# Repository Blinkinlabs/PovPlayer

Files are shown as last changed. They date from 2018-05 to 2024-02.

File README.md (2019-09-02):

# PovPlayer

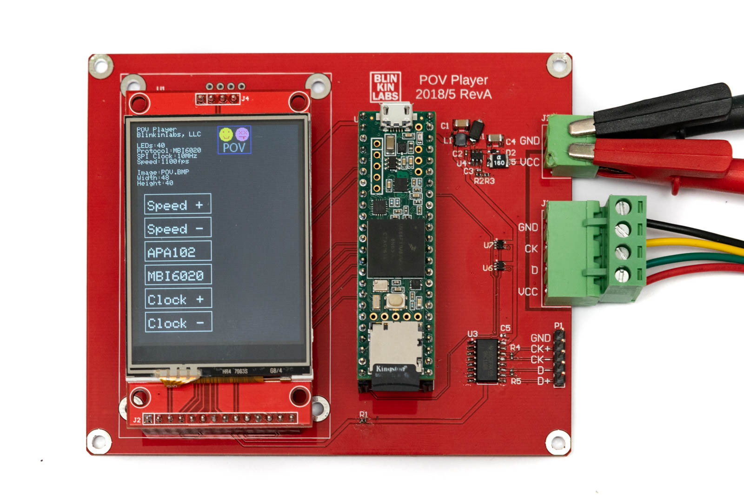
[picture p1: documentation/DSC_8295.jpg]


POV player is a test tool for displaying POV images. It's based on a Teensy 3.6, and uses a generic SPI touchscreen to configure the POV settings.

A PCB file is included, however the project can be built using short jumper wires if desired.

# Hardware needed

* [Teensy 3.6](https://www.pjrc.com/store/teensy36.html)
* [Generic 2.8" SPI touchscreen](https://www.amazon.com/HiLetgo-240X320-Resolution-Display-ILI9341/dp/B073R7BH1B), using ILI9341 driver
* (optional) PCB made from the [project gerbers](https://github.com/Blinkinlabs/PovPlayer/blob/master/releases/2018-05-29%20POV_Player%20RevA%20Gerber.zip)

# Software Setup

Install:

*  [Arduino](https://www.arduino.cc/)
*  [Teensyduino](https://www.pjrc.com/teensy/teensyduino.html)
*  Adafruit_ILI9341 library for Arduino- this might come with Teensyduino
*  XPT2046_Touchscreen library for Arduino- this might come with Teensyduino

Download or clone this respoitory, then open the [project sketch sketch](https://github.com/Blinkinlabs/PovPlayer/tree/master/SPI_POV) in Arduino and upload it to the Teensy 3.6

# Usage

See the [Usage manual](https://github.com/Blinkinlabs/PovPlayer/raw/master/releases/2018-06-05%20POV%20Player%20Manual%20RevA.pdf)

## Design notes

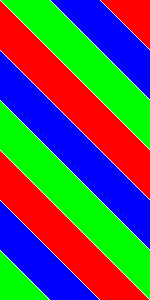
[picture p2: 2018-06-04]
sample images/rgb stripes.bmp

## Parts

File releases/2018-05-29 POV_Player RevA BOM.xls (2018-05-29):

PartType | Designator | Comment | Description | ComponentLink2URL | Pins | LibRef | Manufacturer | Quantity | Model:Footprint
CAP 47uF 16V 1210(3225) | C1, C4 | CAP 47uF 16V 1210(3225) | CAP 47uF 16V ±20% 1210 (3225 Metric) Thickness 2.8mm SMD |  | 2.0 | CMP-1038-02296-1 |  | 2.0 | Chip Capacitor, Body 3.2x2.5mm, Height 2.8mm, IPC High Density
CAP 100nF 25V 0402(1005) | C2 | CAP 100nF 25V 0402(1005) | CAP 100nF 25V ±20% 0402 (1005 Metric) Thickness 0.6mm SMD |  | 2.0 | CMP-1034-02073-1 |  | 1.0 | Chip Capacitor, Body 1.0x0.5mm, Height 0.6mm, IPC High Density
CAP 33pF 25V 0402(1005) | C3 | CAP 33pF 25V 0402(1005) | CAP 33pF 25V ±5% 0402 (1005 Metric) Thickness 0.6mm SMD |  | 2.0 | CMP-1034-00998-1 |  | 1.0 | Chip Capacitor, Body 1.0x0.5mm, Height 0.6mm, IPC High Density
CAP 100nF 10V 0402(1005) | C5 | CAP 100nF 10V 0402(1005) | CAP 100nF 10V ±10% 0402 (1005 Metric) Thickness 0.6mm SMD |  | 2.0 | CMP-1034-02065-1 |  | 1.0 | Chip Capacitor, Body 1.0x0.5mm, Height 0.6mm, IPC High Density
1N4148WT | D1, D2 | 1N4148WT | High Conductance Fast Switching Diode, 75 V, -55 to 150 degC, 2-Pin SOD523F, RoHS | http://www.fairchildsemi.com/ds/1N/1N4148WT.pdf | 2.0 | CMP-0881-00001-1 | Fairchild Semiconductor | 2.0 | SMD, 2-Leads, Body 1.2x0.8mm, Height 0.7mm
1757268 | J1 | 1757268 | TERM BLOCK HDR 4POS 90DEG 5.08MM | 1757268_06_en_00.pdf | 4.0 | 1757268 | Phoenix Contact | 1.0 | TERM BLOCK HDR 4POS 90DEG 5.08MM
Power In | J2 | Power In | TERM BLOCK HDR 2POS 90DEG 5.08MM | 1757268_06_en_00.pdf | 2.0 | 1757242 | Phoenix Contact | 1.0 | TERM BLOCK HDR 2POS 90DEG 5.08MM
SWPA3010S100MT | L1 | SWPA3010S100MT | Wire Wound SMD Power Inductors 3010 3.0×3.0×1.0 10uH, .75A |  | 2.0 | SWPA3010S100MT |  | 1.0 | Wire Wound SMD Power Inductor 3.0×3.0×1.0
PHT-105-02-L-S | P1 | PHT-105-02-L-S | Press Fit Header, Through-hole, Vertical, -55 to 125 degC, 2.54 mm Pitch, 5-Pin, Male, RoHS | http://www.samtec.com/documents/webfiles/pdf/pht.pdf | 5.0 | CMP-1024-00186-1 | Samtec | 1.0 | Press Fit Socket Assembly, 1x5 Pins, Vertical, 2.54mm Pitch, Male
47R 5% 0402(1005) | R1 | 47R 5% 0402(1005) | 47R 0.063W 5% 0402 (1005 Metric) SMD |  | 2.0 | CMP-1011-00042-1 |  | 1.0 | Chip Resistor, Body 1.0x0.5mm, IPC Medium Density
127K 1% 0402(1005) | R2 | 127K 1% 0402(1005) | 127K 0.063W 1% 0402 (1005 Metric) SMD |  | 2.0 | CMP-1011-00747-1 |  | 1.0 | Chip Resistor, Body 1.0x0.5mm, IPC High Density
23K7 1% 0402(1005) | R3 | 23K7 1% 0402(1005) | 23K7 0.063W 1% 0402 (1005 Metric) SMD |  | 2.0 | CMP-1011-00663-1 |  | 1.0 | Chip Resistor, Body 1.0x0.5mm, IPC High Density
120R 5% 0402(1005) | R4, R5 | 120R 5% 0402(1005) | 120R 0.063W 5% 0402 (1005 Metric) SMD |  | 2.0 | CMP-1011-00052-1 |  | 2.0 | Chip Resistor, Body 1.0x0.5mm, IPC Medium Density
2.4" SPI LCD ILI9341 | U1 | 2.4" SPI LCD ILI9341 | Generic 2.4 inch SPI LCD TFT serial module 240x320 with touch ILI9341 |  | 18.0 | 2.4" SPI LCD ILI9341 |  | 1.0 | Generic 2.4 inch SPI LCD TFT serial module 240x320 with touch ILI9341
TEENSY_3.6 | U2 | TEENSY_3.6 | Teensy 3.6 |  | 48.0 | TEENSY_3.6 |  | 1.0
SN65C1168ENS | U3 | SN65C1168ENS | Dual Differential Driver and Receiver with +/-15-kV IEC ESD Protection, 2 TX / 2 RX, 5V, -40 to 85 degC, 16-Pin SO (NS), Green (RoHS & no Sb/Br) | http://www.ti.com/litv/pdf/msop002a | 16.0 | CMP-0310-00409-2 | Texas Instruments | 1.0 | SOIC,16-Leads,Body 10.5x5.6mm,Pitch 1.27mm,IPC Medium Density
BL9352A | U4 | BL9352A | 45V, 1.6MHz, 600mA Step-Down Converter |  | 6.0 | BL9352A |  | 1.0 | SOT23, 6-Leads, Body 2.92x2.80mm, Pitch 0.95mm, IPC Medium Density
nSMD020-30V | U5 | nSMD020-30V | 0.2A 30V Self-healing fuse |  | 2.0 | nSMD020-30V | Alpha-Top Technology Corp. | 1.0 | 0.2A 30V Self-healing fuse
74LVC1G17GW | U6, U7 | 74LVC1G17GW | Single Schmitt Trigger Buffer, 1.65 to 5.5 V, -40 to 125 degC, 5-Pin TSSOP (SOT353-1), RoHS, Tape and Reel |  | 5.0 | CMP-2000-05689-1 | NXP Semiconductors | 2.0 | TSSOP, 5-Leads, Body 2.25x1.35mm, Pitch 0.65mm, IPC High Density

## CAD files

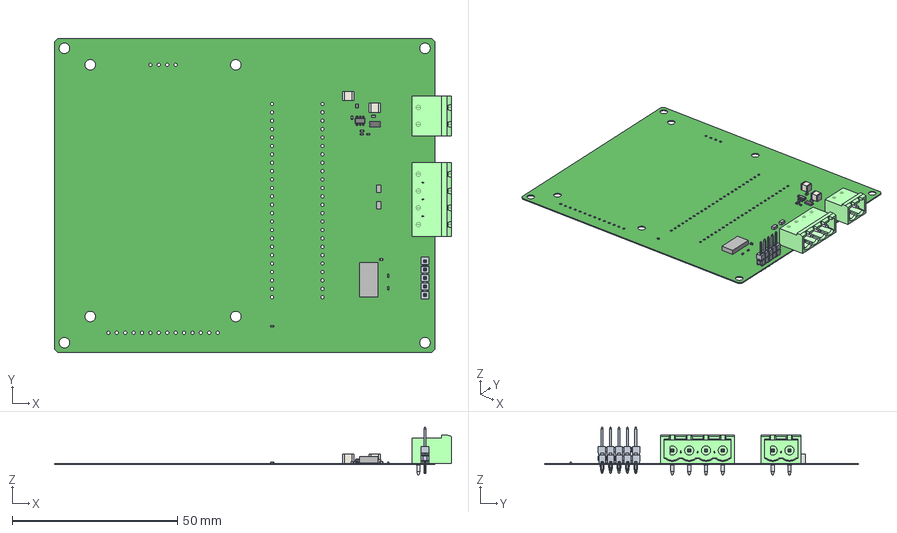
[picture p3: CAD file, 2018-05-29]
releases/2018-05-29 POV_Player RevA.step
120.0 x 95.0 x 14.4 mm
Board
Extruded x 35
Fuse_1206_v1
Open_CASCADE_STEP_translator_6.8_3.1.1
Leader x 6
PHT-105-02-X-S
mstba_2.5-2-g-5.08
mstba_2.5-4-g-5.08

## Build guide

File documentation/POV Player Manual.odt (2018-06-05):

POV Player

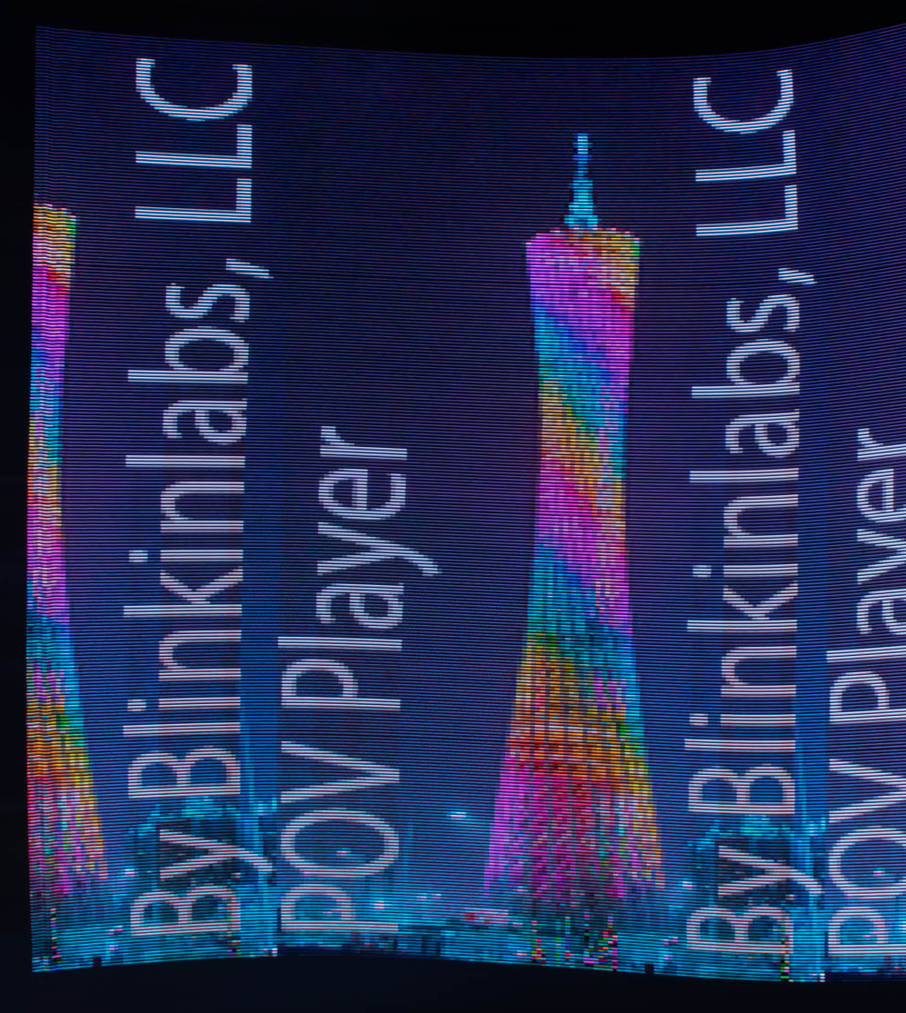
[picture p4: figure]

Blinkinlabs LLC
Revision A 2018/06/05

# Introduction

The POV Player is a prototyping tool for developing a persistence of vision artwork.

Specifications:

- Maximum LED count: 500 LEDs
- Outputs: 1
- Typical framerate (output lines per second): 1100
- Maximum POV image size: Maximum ~150kB (500 RGBLEDs x 100frames)
- Maximum SPI output speed: 30MHz
- Input power range: 5-24V
- Image format: 24-bit uncompressed bitmap

It supports the following LED types:

- APA102/SK9822
- MBI6020 (used in dot pixel product)

# Absolute Maximum Ratings

The absolute maximum ratings indicated sustained limits beyond which damage to the device may occur.

Parameter | Description | Min | Max | Units
VCC | Input Voltage (J2 connector) | -0.3 | 28 | V
ILED | LED output current (J1 connector) | | 10 | A

# Recommended Operating Conditions

For proper operation, the device should be used within the recommended conditions.

Parameter | Description | Min | Max | Units
VCC | Input Voltage (J2 connector) | 5 | 24 | V
ILED | LED output current (J1 connector) | | 8 | A

*Note: The POV Player is designed to be powered from whatever power supply is used for the LEDs. For APA102/SK9822 strips, this is usually 5V. For the Dot Pixels (MBI6020), the pixels are powered from AC power, so an external power supply should be used. The 12V supply in the existing control box can be used to power the player.

# Quick start guide

1. Connect either the SK9822 or Dot Pixels, using the steps listed in the section ‘Connection diagram (Dot Pixels)’ or ‘Connection diagram (SK9822 strip)’.
2. If the microSD card is inserted in the player, remove it.
3. Power on the unit. By default, it will play back a slow test pattern, cycling up to 500 LEDs through red, green, and blue. Note that the default protocol is MBI6020, so if an SK9822 strip is attached, you will need to follow the instructions in the ‘Status Information’ section to switch to APA102/SK9822 mode.
4. Use the instructions in the ‘Status Information’ guide to test adjusting the playback speed and clock speed. Also Try increasing the clock speed until the LEDs no longer update properly- that will show the maximum speed supported by the hardware.
5. Once the setup is working with the demo pattern, the next step is to load a POV image. Prepare a microSD card with an image using the steps listed in the section ‘Image preparation’
6. Place the microSD card in the controller, and turn the power back on.
7. Enjoy the POV effect!

# Image Preparation

The POV player can load a single POV image from the microSD card. The image must be formatted as a 24-bit, uncompressed bitmap. The LED count is determined by the image height, and the number of POV frames is determined by the image width. For example, if there are 40 LEDs in the system, an image with height 40 should be used. If a small image should be repeated multiple times along the LED strip, simply create an image with multiple copies arranged in a vertical row.

Here are the steps for exporting a compatible bitmap image from Photoshop:

1. Insert the microSD card into the computer.
2. Launch photoshop, then load the desired image.
3. From the file menu, select ‘Save As’
4. On the ‘Save as type’ option, select ‘BMP’
5. Change the image name to ‘pov.bmp’, and select the root of the SD card drive (for example E:\ on Windows) as the location to save it. Click ‘Save’
6. On the ‘BMP Options’ dialog, make sure the File Format is set to ‘Windows’, the Depth is set to ‘24 Bit’, and no other options are selected. Click ‘OK’
7. Eject the microSD card from the computer, and place it in the Player.

# Connection diagram (Dot Pixels)

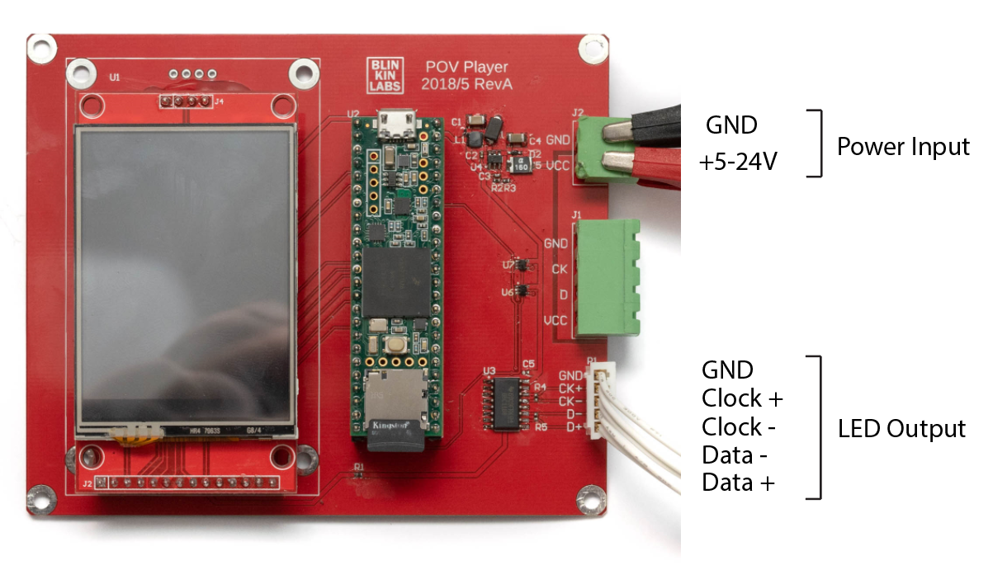
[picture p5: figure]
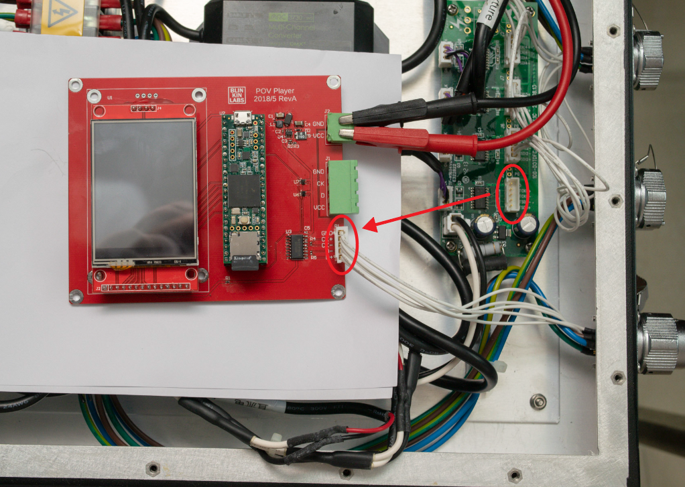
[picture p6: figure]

For Dot Pixels, connect a 5-24V power supply to the connector J2. The 12V supply inside the existing metal control box can be used for this. Then, disconnect the white cable from inside the metal control box, and connect it to output P1. Be sure to plug the connector in the right orientation- the pins are labeled on both the original adapter board and the POV Player. In this configuration, the LED power is connected directly to the dot pixel strip, bypassing the POV player.

Note: The P1 connector outputs an RS422 differential signal, suitable for controlling the Dot Pixel samples.

Caution: The Dot Pixels are powered by 220V AC wall power. Be extremely careful when working with this style of pixel, and be sure to mount the POV Player such that none of its electrical connections touch any of the connections in the existing controller box.

# Connection diagram (SK9822 strip)

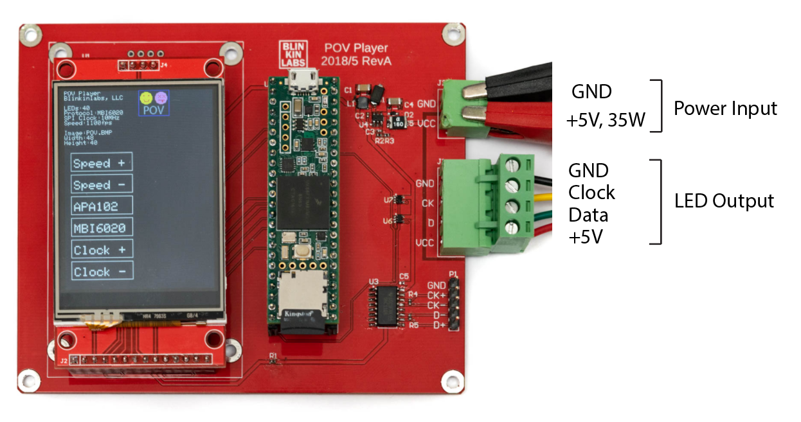
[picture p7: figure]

For SK9822 strip, connect a 5V power supply rated at 35W (7A) or greater to the connector J2. Then, connect the SK9822 strip to the connector J2. In this configuration, the LED strip is powered directly from the board, so no further wiring is needed.

Note: The J1 connector outputs a single ended, 5V TTL signal suitable for common LED strips.

# Status Interface

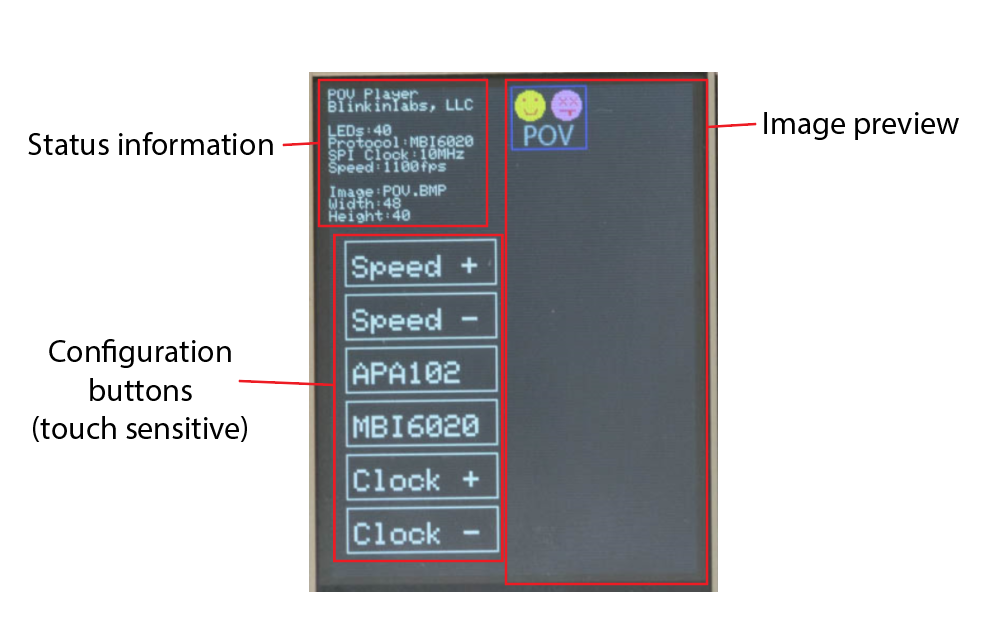
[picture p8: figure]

## Status Information

The status information section displays the current LED configuration, including LED count, protocol, SPI clock speed, image file name, and image dimensions.

## Configuration Buttons

The POV player can be configured by using the on-screen buttons. Simply press a button to change it’s setting.

Button | Description
SPEED + | Increase the POV Speed. If the POV speed is less than 10, it will be incremented by 1 each time the button is pressed. If the POV speed is between 10 and 100, it will be increased by 10 each time the button is pressed. If the POV speed is equal to or greater than 100, it will be incremented by 100 each time the button is pressed.
SPEED - | Decrease the POV Speed. If the POV speed is less than or equal to 10, it will be decremented by 1 each time the button is pressed. If the POV speed is between 11 and 100, it will be decremented by 10 each time the button is pressed. If the POV speed is greater than 100, it will be decremented by 100 each time the button is pressed. The minimum POV speed is 1.
APA102 | Switch the output protocol to APA102/SK9822 mode. Pressing this will also reset the SPI Clock setting to 16MHz.
MBI6020 | Switch the output protocol to MBI6020 mode. Pressing this will also reset the SPI Clock setting to 10MHz. Note that the dot pixels should be connected to the player and powered on before switching to this mode, because the player needs to send configuration information to them before they can be used. Also note that the MBI6020 controllers in the dot pixels can become unresponsive, if data from a different output protocol is sent to them. In that case, turn the AC power off and then on again to reset the dot pixel controllers.
Clock + | Increase the SPI clock speed. The speed will be increased by 1 MHz each time the button is pressed. The maximum workable speed that the player can output depends on the LED type.
Clock - | Decrease the SPI clock speed. The speed will be decreased by 1 MHz each time the button is pressed. The minimum clock speed is 1 MHz.

## Image Preview

The image preview shows a color representation of the image that is currently displayed on the screen. If the image is larger than 118x318, only the top-left corner of the image will be shown on the screen, however the full image will still be sent to the pixels.

Blinkinlabs, LLC 7/7 POV Player Rev A, 2018/06/05

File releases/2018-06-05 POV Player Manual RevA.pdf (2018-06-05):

# POV Player

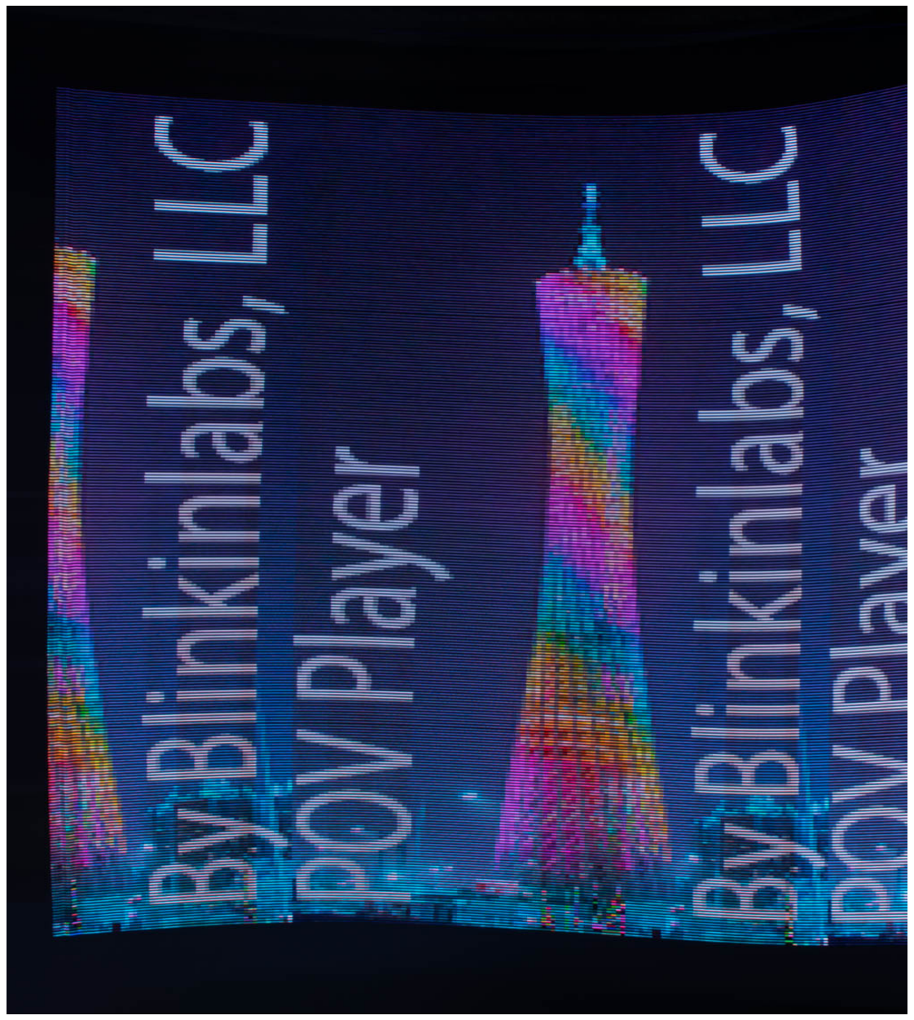
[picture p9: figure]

## Blinkinlabs LLC Revision A 2018/06/05

## 1 Introduction

The POV Player is a prototyping tool for developing a persistence of vision artwork.

Specifications:
- Maximum LED count: 500 LEDs
- Outputs: 1
- Typical framerate (output lines per second): 1100
- Maximum POV image size: Maximum ~150kB (500 RGBLEDs x 100frames)
- Maximum SPI output speed: 30MHz
- Input power range: 5-24V
- Image format: 24-bit uncompressed bitmap

It supports the following LED types:
- APA102/SK9822
- MBI6020 (used in dot pixel product)

## 2 Absolute Maximum Ratings

The absolute maximum ratings indicated sustained limits beyond which damage to the device may occur.
Parameter | Description | Min | Max | Units
VCC | Input Voltage (J2 connector) | -0.3 | 28 | V
ILED | LED output current (J1 connector) | | 10 | A

## 3 Recommended Operating Conditions

For proper operation, the device should be used within the recommended conditions.
Parameter | Description | Min | Max | Units
VCC | Input Voltage (J2 connector) | 5 | 24 | V
ILED | LED output current (J1 connector) | | 8 | A
*Note: The POV Player is designed to be powered from whatever power supply is used for the LEDs. For APA102/SK9822 strips, this is usually 5V. For the Dot Pixels (MBI6020), the pixels are powered from AC power, so an external power supply should be used. The 12V supply in the existing control box can be used to power the player.
Blinkinlabs, LLC | 2/7 | POV Player Rev A, 2018/06/05

## 4 Quick start guide

1. Connect either the SK9822 or Dot Pixels, using the steps listed in the section ‘Connection diagram (Dot Pixels)’ or ‘Connection diagram (SK9822 strip)’.
2. If the microSD card is inserted in the player, remove it.
3. Power on the unit. By default, it will play back a slow test pattern, cycling up to 500 LEDs through red, green, and blue. Note that the default protocol is MBI6020, so if an SK9822 strip is attached, you will need to follow the instructions in the ‘Status Information’ section to switch to APA102/SK9822 mode.
4. Use the instructions in the ‘Status Information’ guide to test adjusting the playback speed and clock speed. Also Try increasing the clock speed until the LEDs no longer update properly- that will show the maximum speed supported by the hardware.
5. Once the setup is working with the demo pattern, the next step is to load a POV image. Prepare a microSD card with an image using the steps listed in the section ‘Image preparation’
6. Place the microSD card in the controller, and turn the power back on.
7. Enjoy the POV effect!

## 5 Image Preparation

The POV player can load a single POV image from the microSD card. The image must be formatted as a 24-bit, uncompressed bitmap. The LED count is determined by the image height, and the number of POV frames is determined by the image width. For example, if there are 40 LEDs in the system, an image with height 40 should be used. If a small image should be repeated multiple times along the LED strip, simply create an image with multiple copies arranged in a vertical row.

Here are the steps for exporting a compatible bitmap image from Photoshop:

1. Insert the microSD card into the computer.
2. Launch photoshop, then load the desired image.
3. From the file menu, select ‘Save As’
4. On the ‘Save as type’ option, select ‘BMP’
5. Change the image name to ‘pov.bmp’, and select the root of the SD card drive (for example E:\ on Windows) as the location to save it. Click ‘Save’
6. On the ‘BMP Options’ dialog, make sure the File Format is set to ‘Windows’, the Depth is set to ‘24 Bit’, an no other options are selected. Click ‘OK’
7. Eject the microSD card from the computer, and place it in the Player.
Blinkinlabs, LLC | 3/7 | POV Player Rev A, 2018/06/05

## 6 Connection diagram (Dot Pixels)

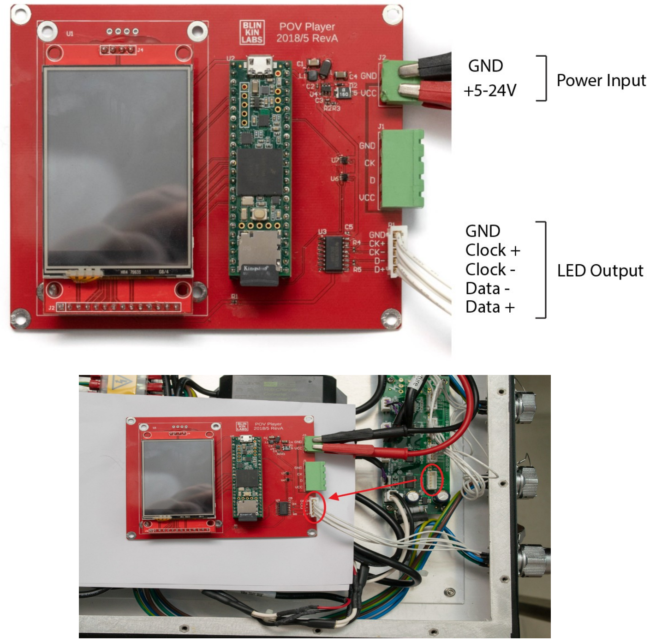
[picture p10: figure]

For Dot Pixels, connect a 5-24V power supply to the connector J2. The 12V supply inside the existing metal control box can be used for this. Then, disconnect the white cable from inside the metal control box, and connect it to output P1. Be sure to plug the connector in the right orientation- the pins are labeled on both the original adapter board and the POV Player. In this configuration, the LED power is connected directly to the dot pixel strip, bypassing the POV player.

Blinkinlabs, LLC | 4/7 | POV Player Rev A, 2018/06/05

Note: The P1 connector outputs an RS422 differential signal, suitable for controlling the Dot Pixel samples.

Caution: The Dot Pixels are powered by 220V AC wall power. Be extremely careful when working with this style of pixel, and be sure to mount the POV Player such that none of its electrical connections touch any of the connections in the existing controller box.

## 7 Connection diagram (SK9822 strip)

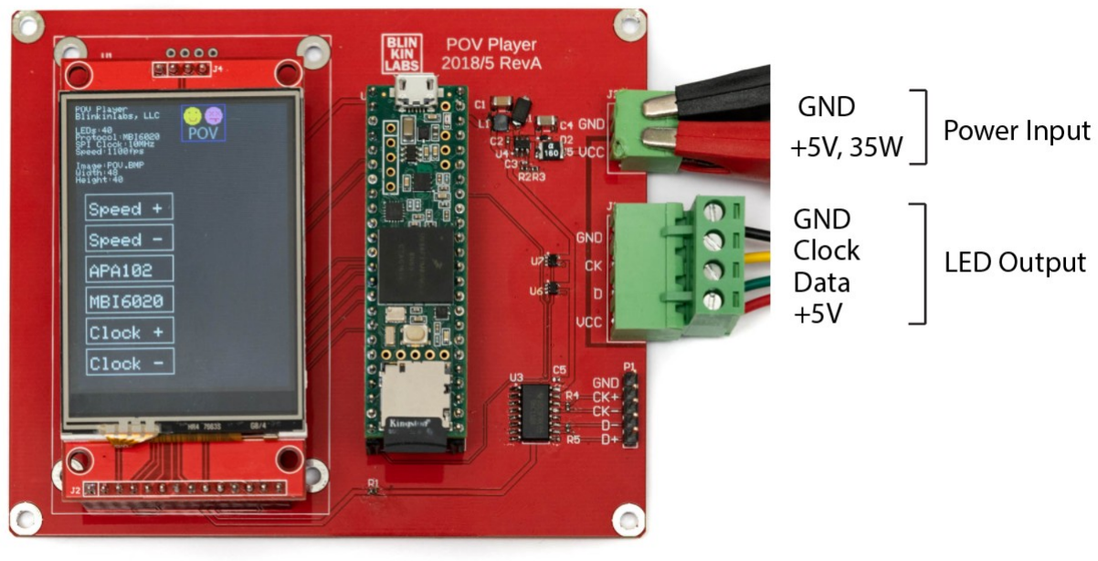
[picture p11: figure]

For SK9822 strip, connect a 5V power supply rated at 35W (7A) or greater to the connector J2. Then, connect the SK9822 strip to the connector J2. In this configuration, the LED strip is powered directly from the board, so no further wiring is needed.

Note: The J1 connector outputs a single ended, 5V TTL signal suitable for common LED strips.

Blinkinlabs, LLC | 5/7 | POV Player Rev A, 2018/06/05

## 8 Status Interface

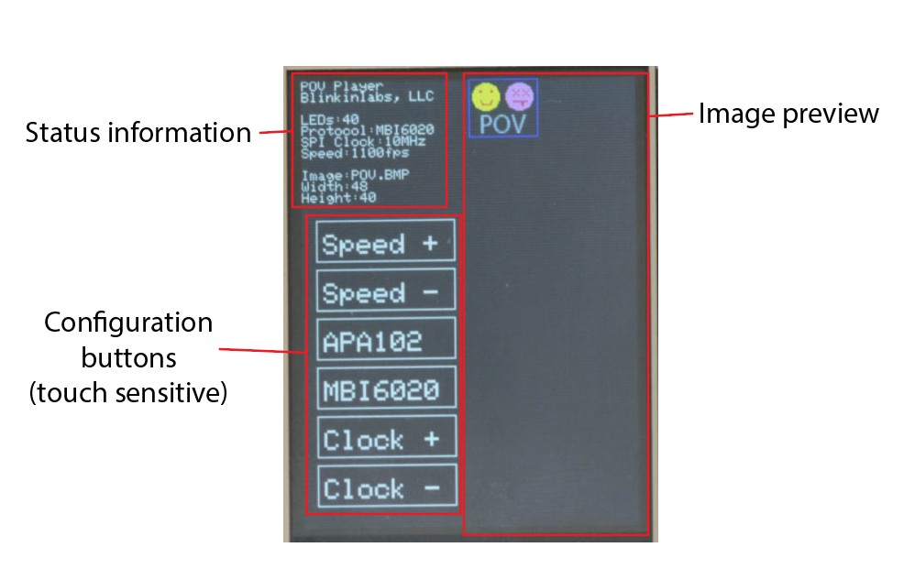
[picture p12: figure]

## Status Information

The status information section displays the current LED configuration, including LED count, protocol, SPI clock speed, image file name, and image dimensions.

## Configuration Buttons

The POV player can be configured by using the on-screen buttons. Simply press a button to change it’s setting.

Button | Description
SPEED + | Increase the POV Speed. If the POV speed is less than 10, it will be incremented by 1 each time the button is pressed. If the POV speed is between 10 and 100, it will be increased by 10 each time the button is pressed. If the POV speed is equal to or greater than 100, it will be incremented by 100 each time the button is pressed.
SPEED - | Decrease the POV Speed. If the POV speed is less than or equal to 10, it will be decremented by 1 each time the button is pressed. If the POV speed is between 11 and 100, it will be decremented by 10 each time the button is pressed. If the POV speed is
Blinkinlabs, LLC | 6/7 | POV Player Rev A, 2018/06/05

| greater than 100, it will be decremented by 100 each time the button is pressed. The minimum POV speed is 1.
APA102 | Switch the output protocol to APA102/SK9822 mode. Pressing this will also reset the SPI Clock setting to 16MHz.
MBI6020 | Switch the output protocol to MBI6020 mode. Pressing this will also reset the SPI Clock setting to 10MHz. Note that the dot pixels should be connected to the player and powered on before switching to this mode, because the player needs to send configuration information to them before they can be used. Also note that the MBI6020 controllers in the dot pixels can become unresponsive, if data from a different output protocol is sent to them. In that case, turn the AC power off and then on again to reset the dot pixel controllers.
Clock + | Increase the SPI clock speed. The speed will be increased by 1 MHz each time the button is pressed. The maximum workable speed that the player can output depends on the LED type.
Clock - | Decrease the SPI clock speed. The speed will be decreased by 1 MHz each time the button is pressed. The minimum clock speed is 1 MHz.

## Image Preview

The image preview shows a color representation of the image that is currently displayed on the screen. If the image is larger than 118x318, only the top-left corner of the image will be shown on the screen, however the full image will still be sent to the pixels.

Blinkinlabs, LLC | 7/7 | POV Player Rev A, 2018/06/05

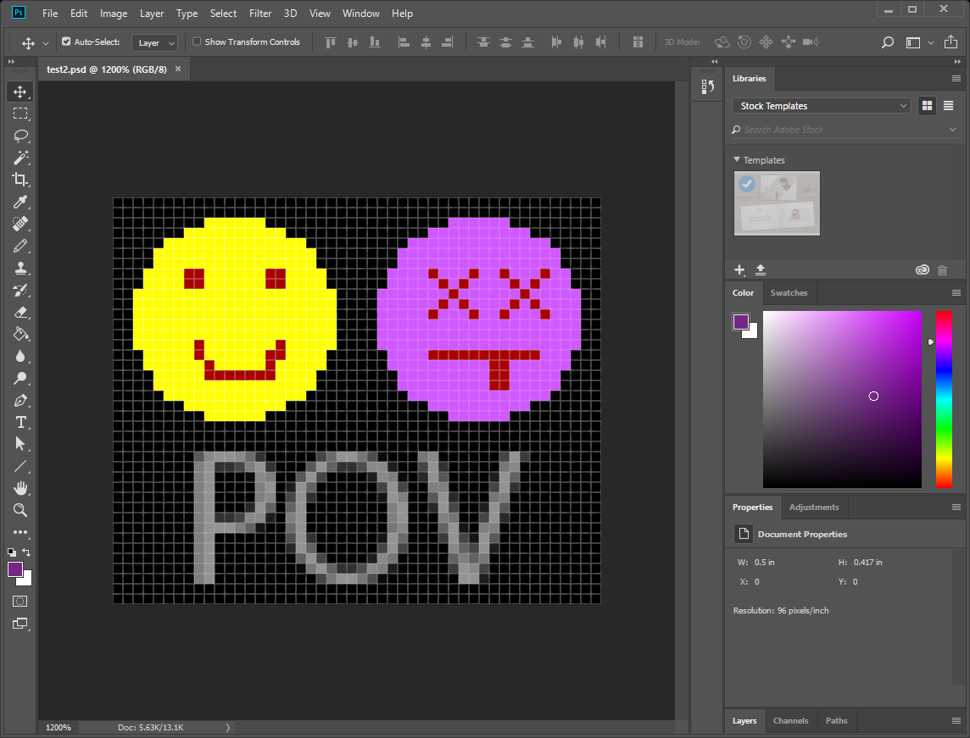
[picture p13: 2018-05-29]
instructions/1. Load in Photoshop.PNG

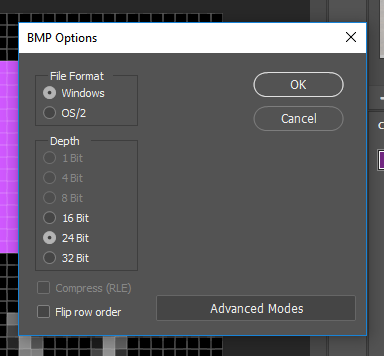
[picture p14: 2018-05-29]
instructions/5. Select 'Windows' format and '24 bit' depth, and then OK.PNG

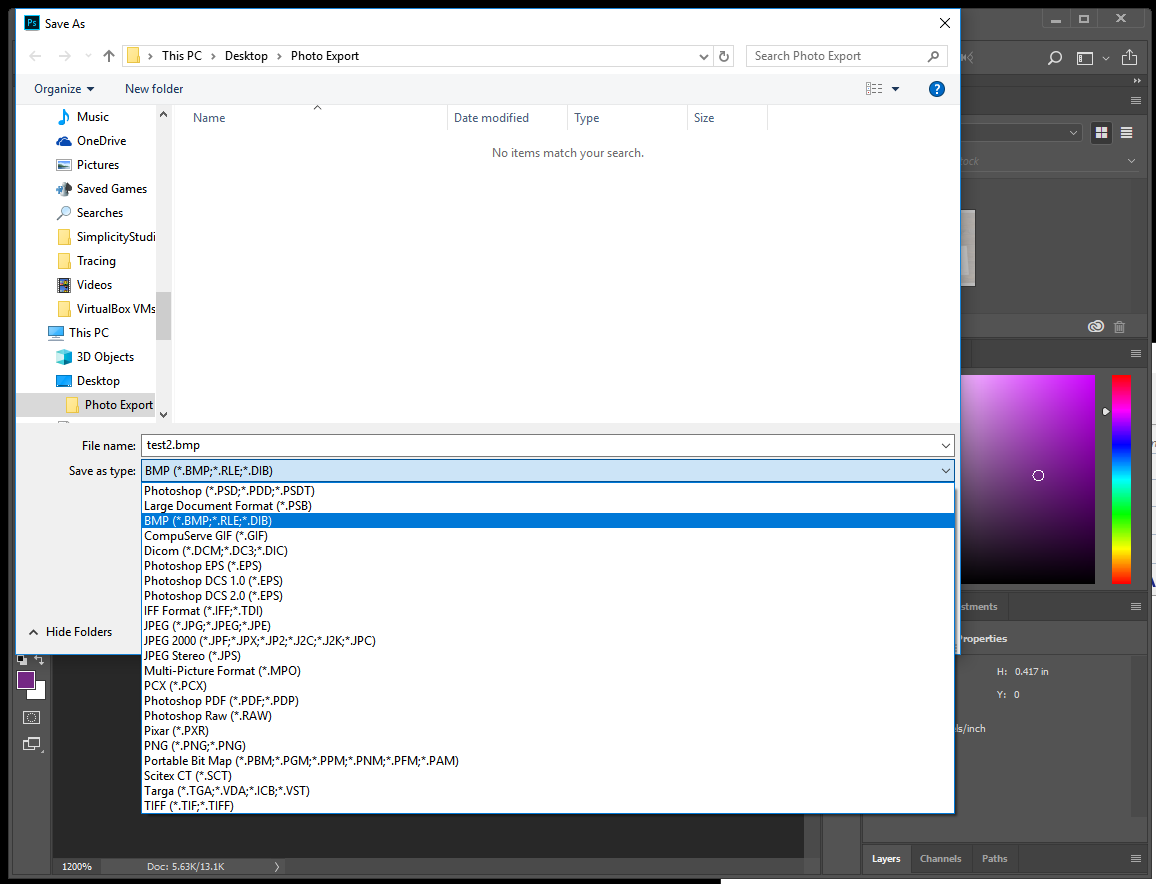
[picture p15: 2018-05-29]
instructions/3. Select bitmap.PNG

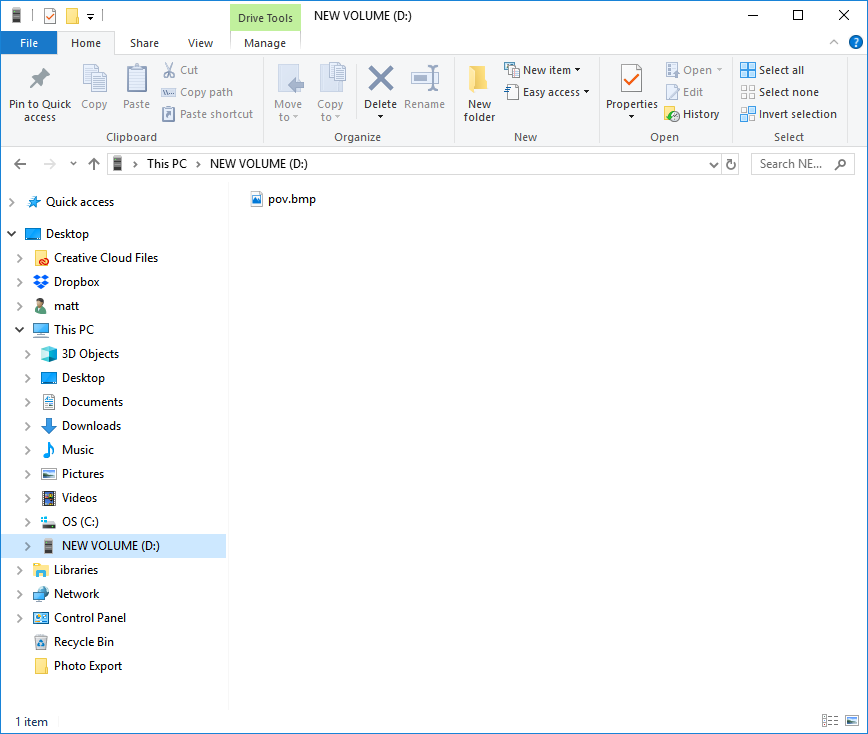
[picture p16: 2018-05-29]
instructions/6 Copy to the microSD card.PNG

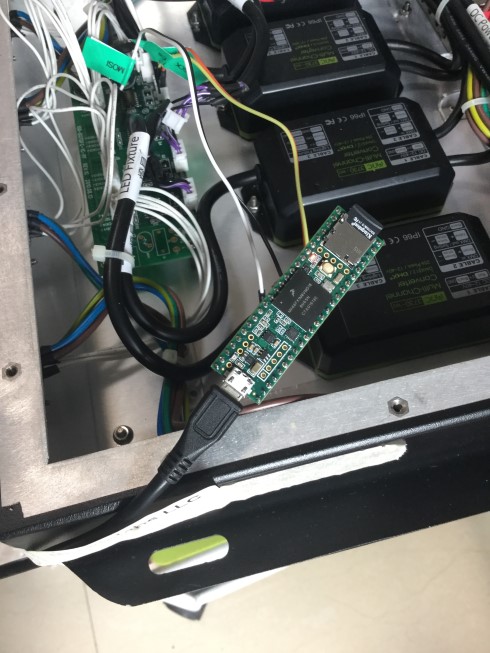
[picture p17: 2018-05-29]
instructions/7 Place microSD card in controller, and reset controller.jpg

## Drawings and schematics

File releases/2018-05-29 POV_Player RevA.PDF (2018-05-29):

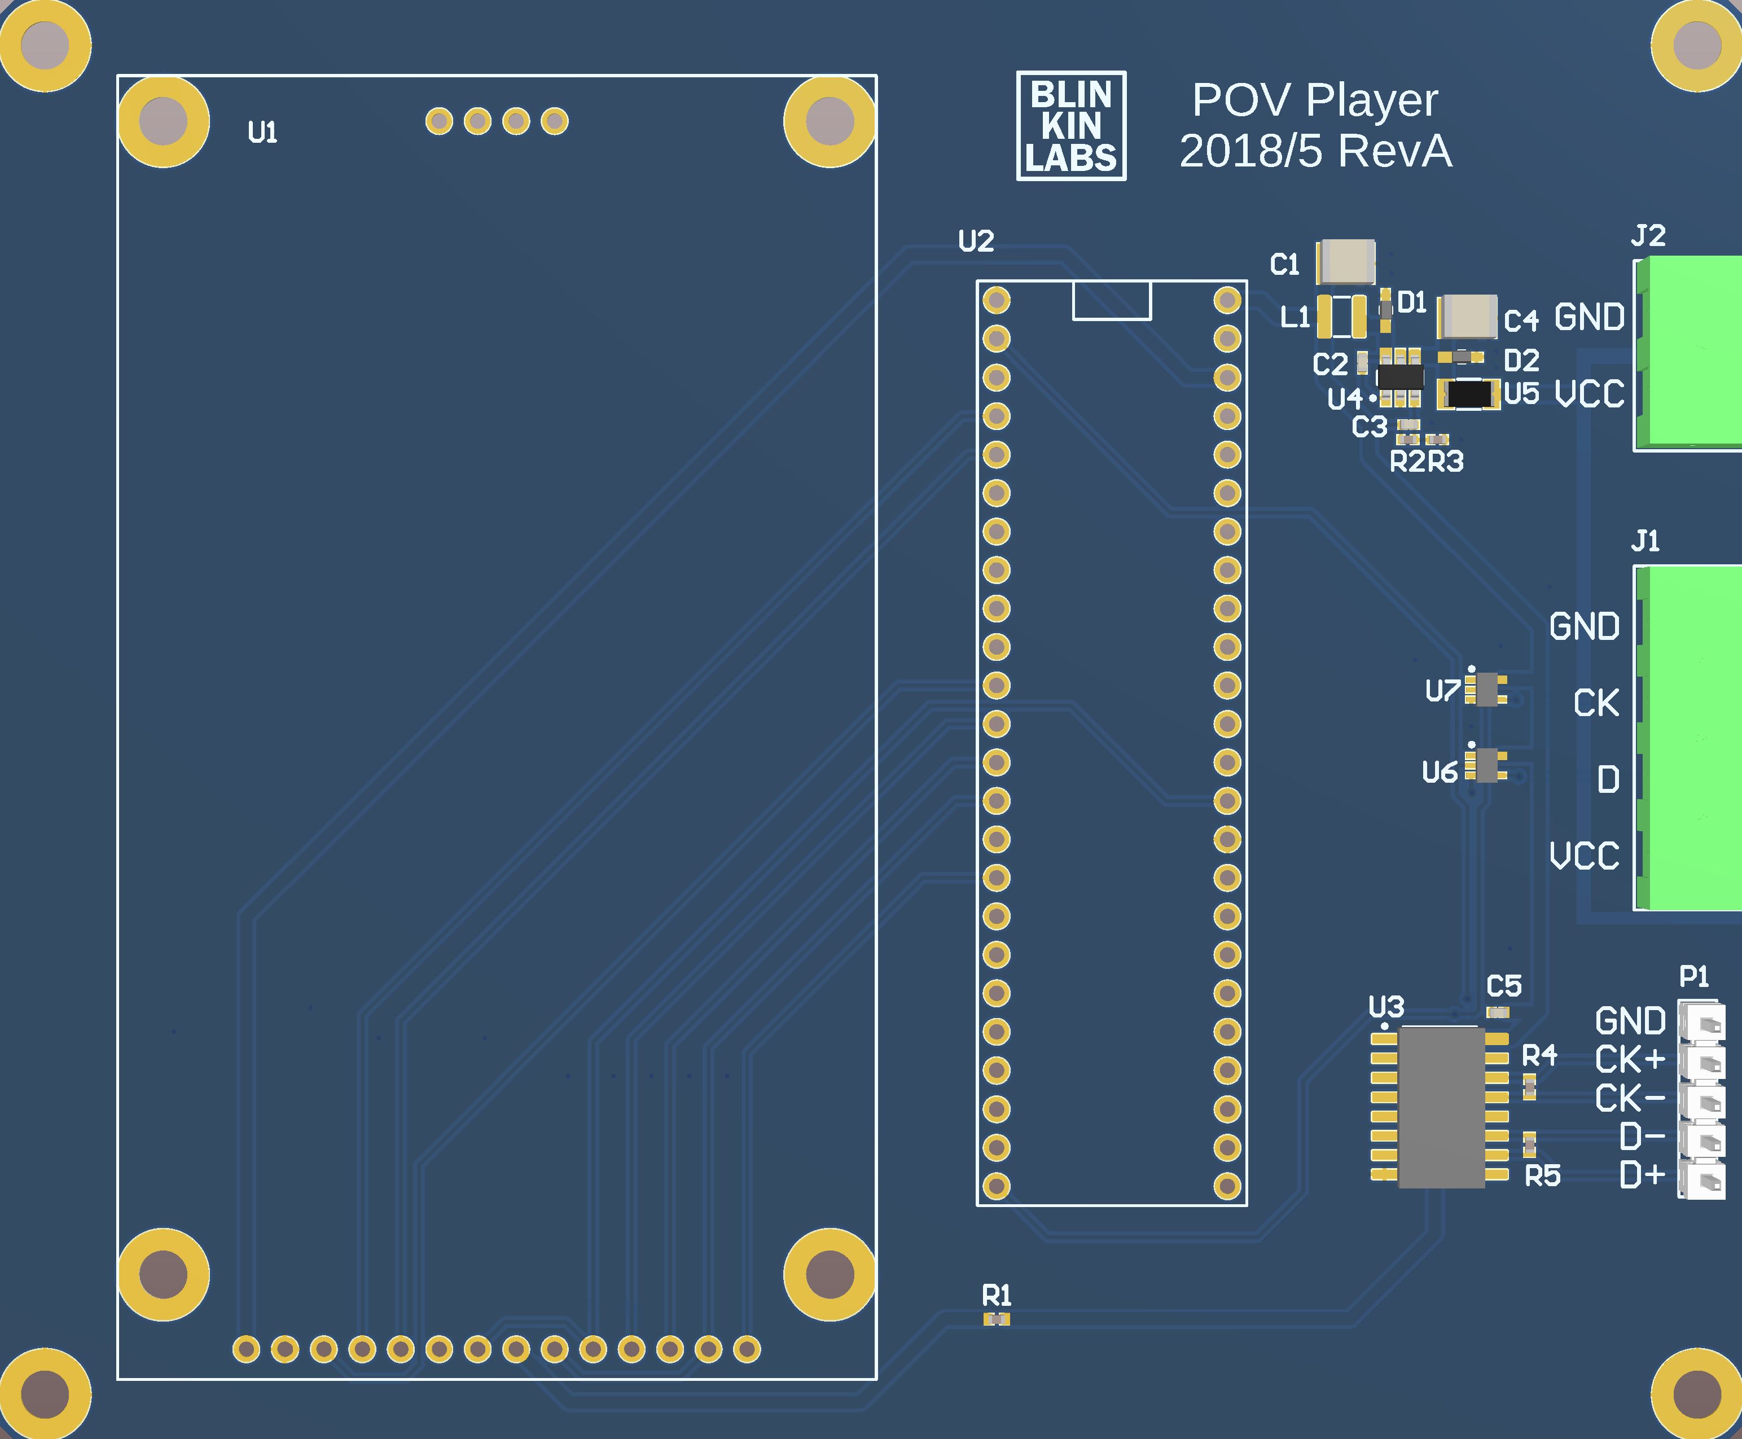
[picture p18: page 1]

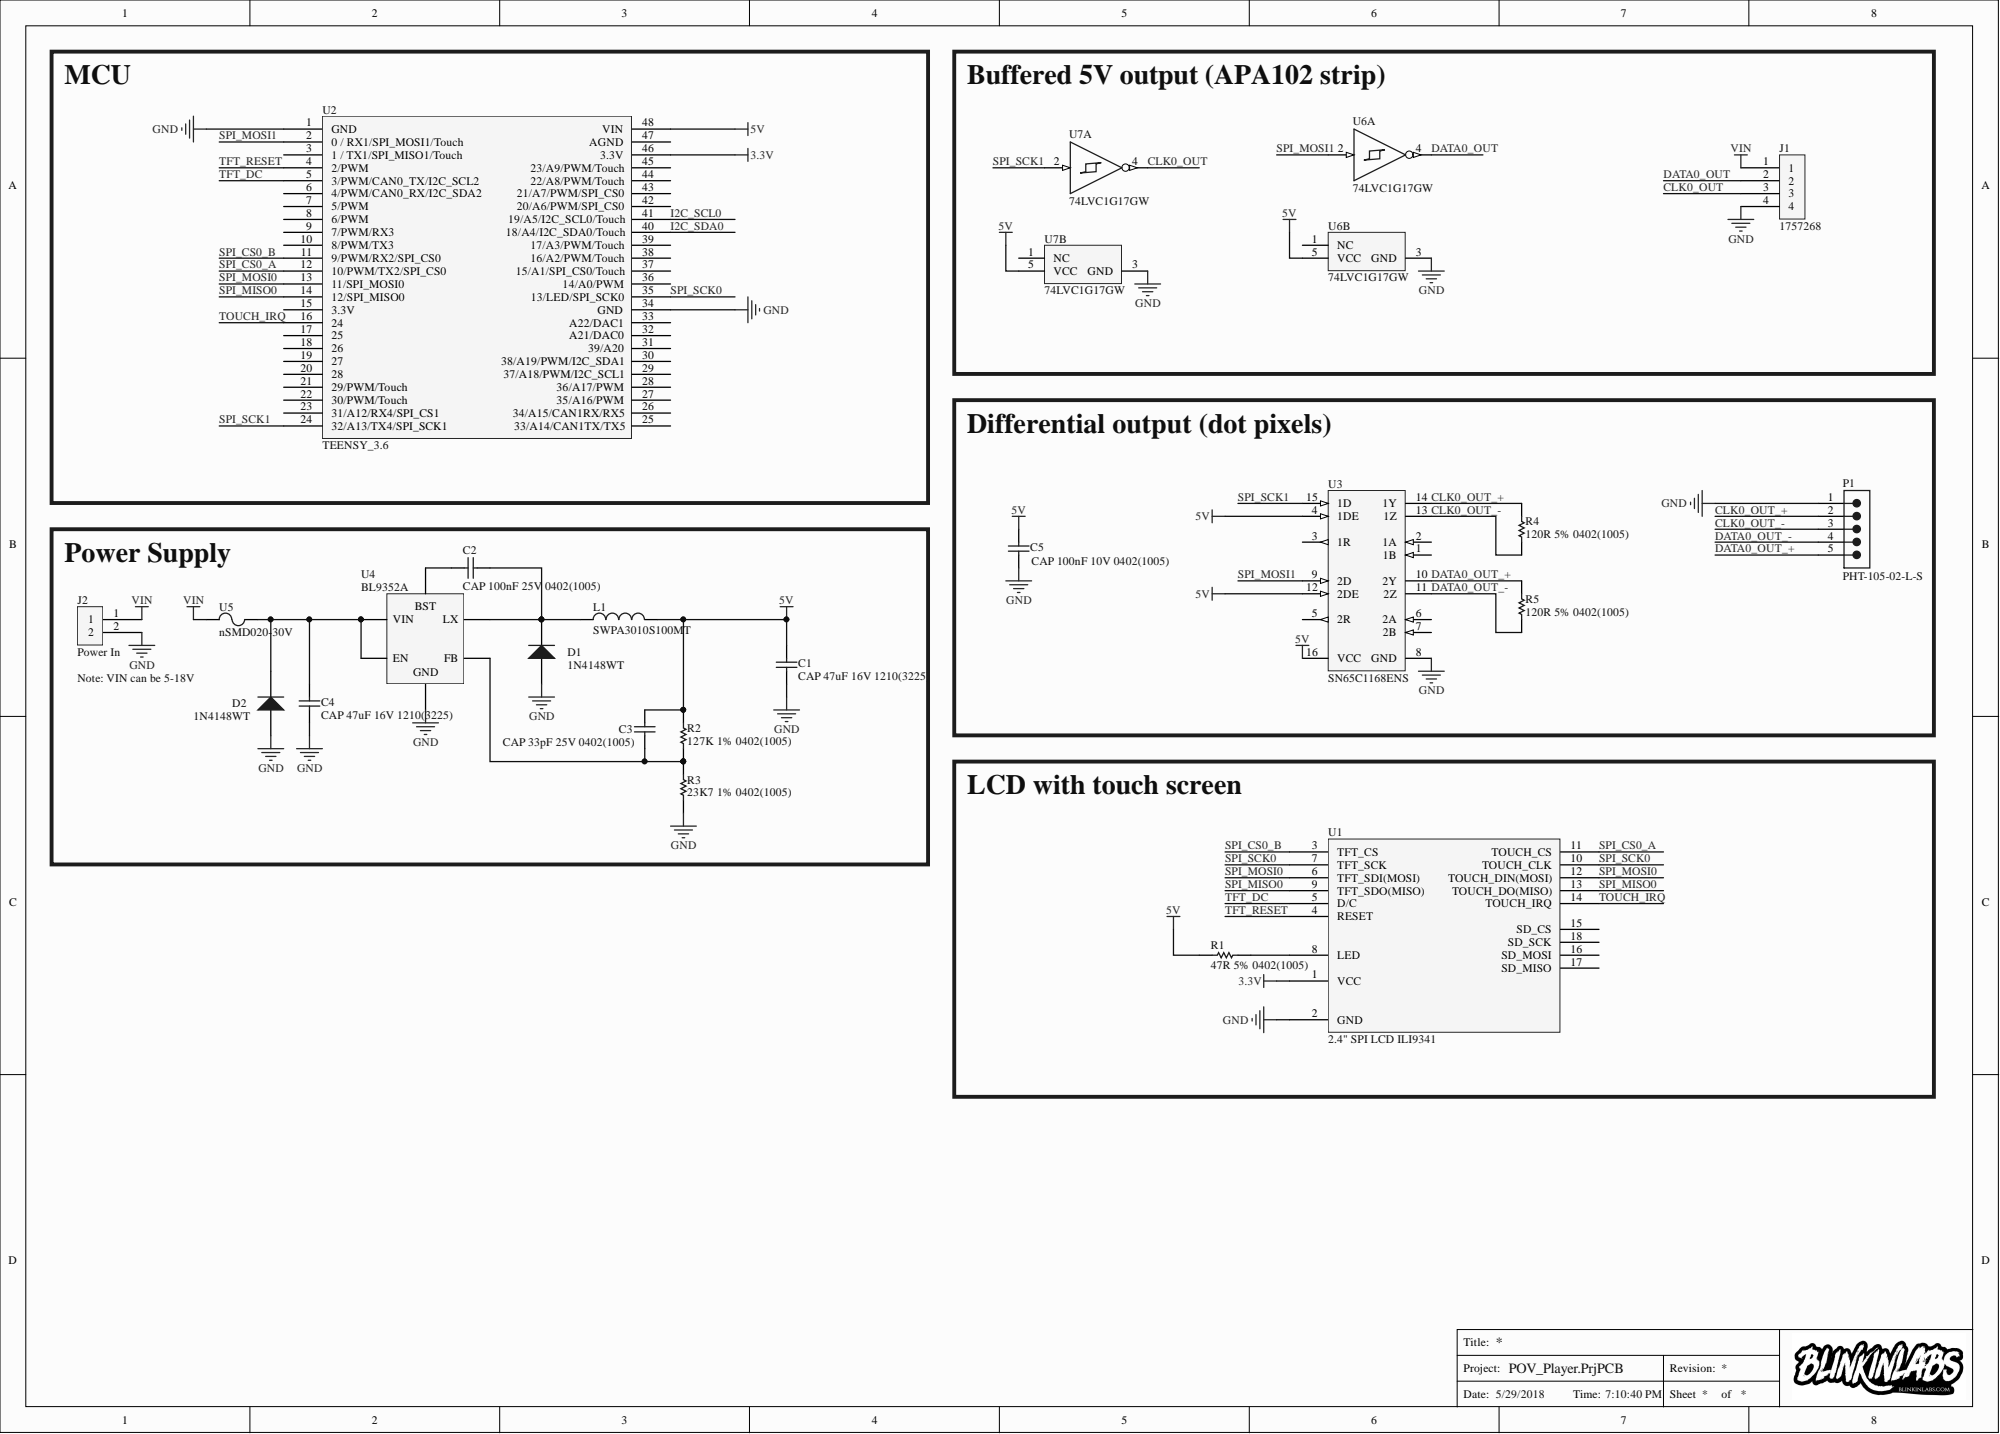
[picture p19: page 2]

Differential output (dot pixels)

LCD with touch screen

Project : P O V_ Pla y e r.PrjPCB | Rev i s i o n : *

Date: 5 / 2 9 / 2 0 1 8 T ime: 7 : 1 0 : 4 0 PM | Sheet * o f *

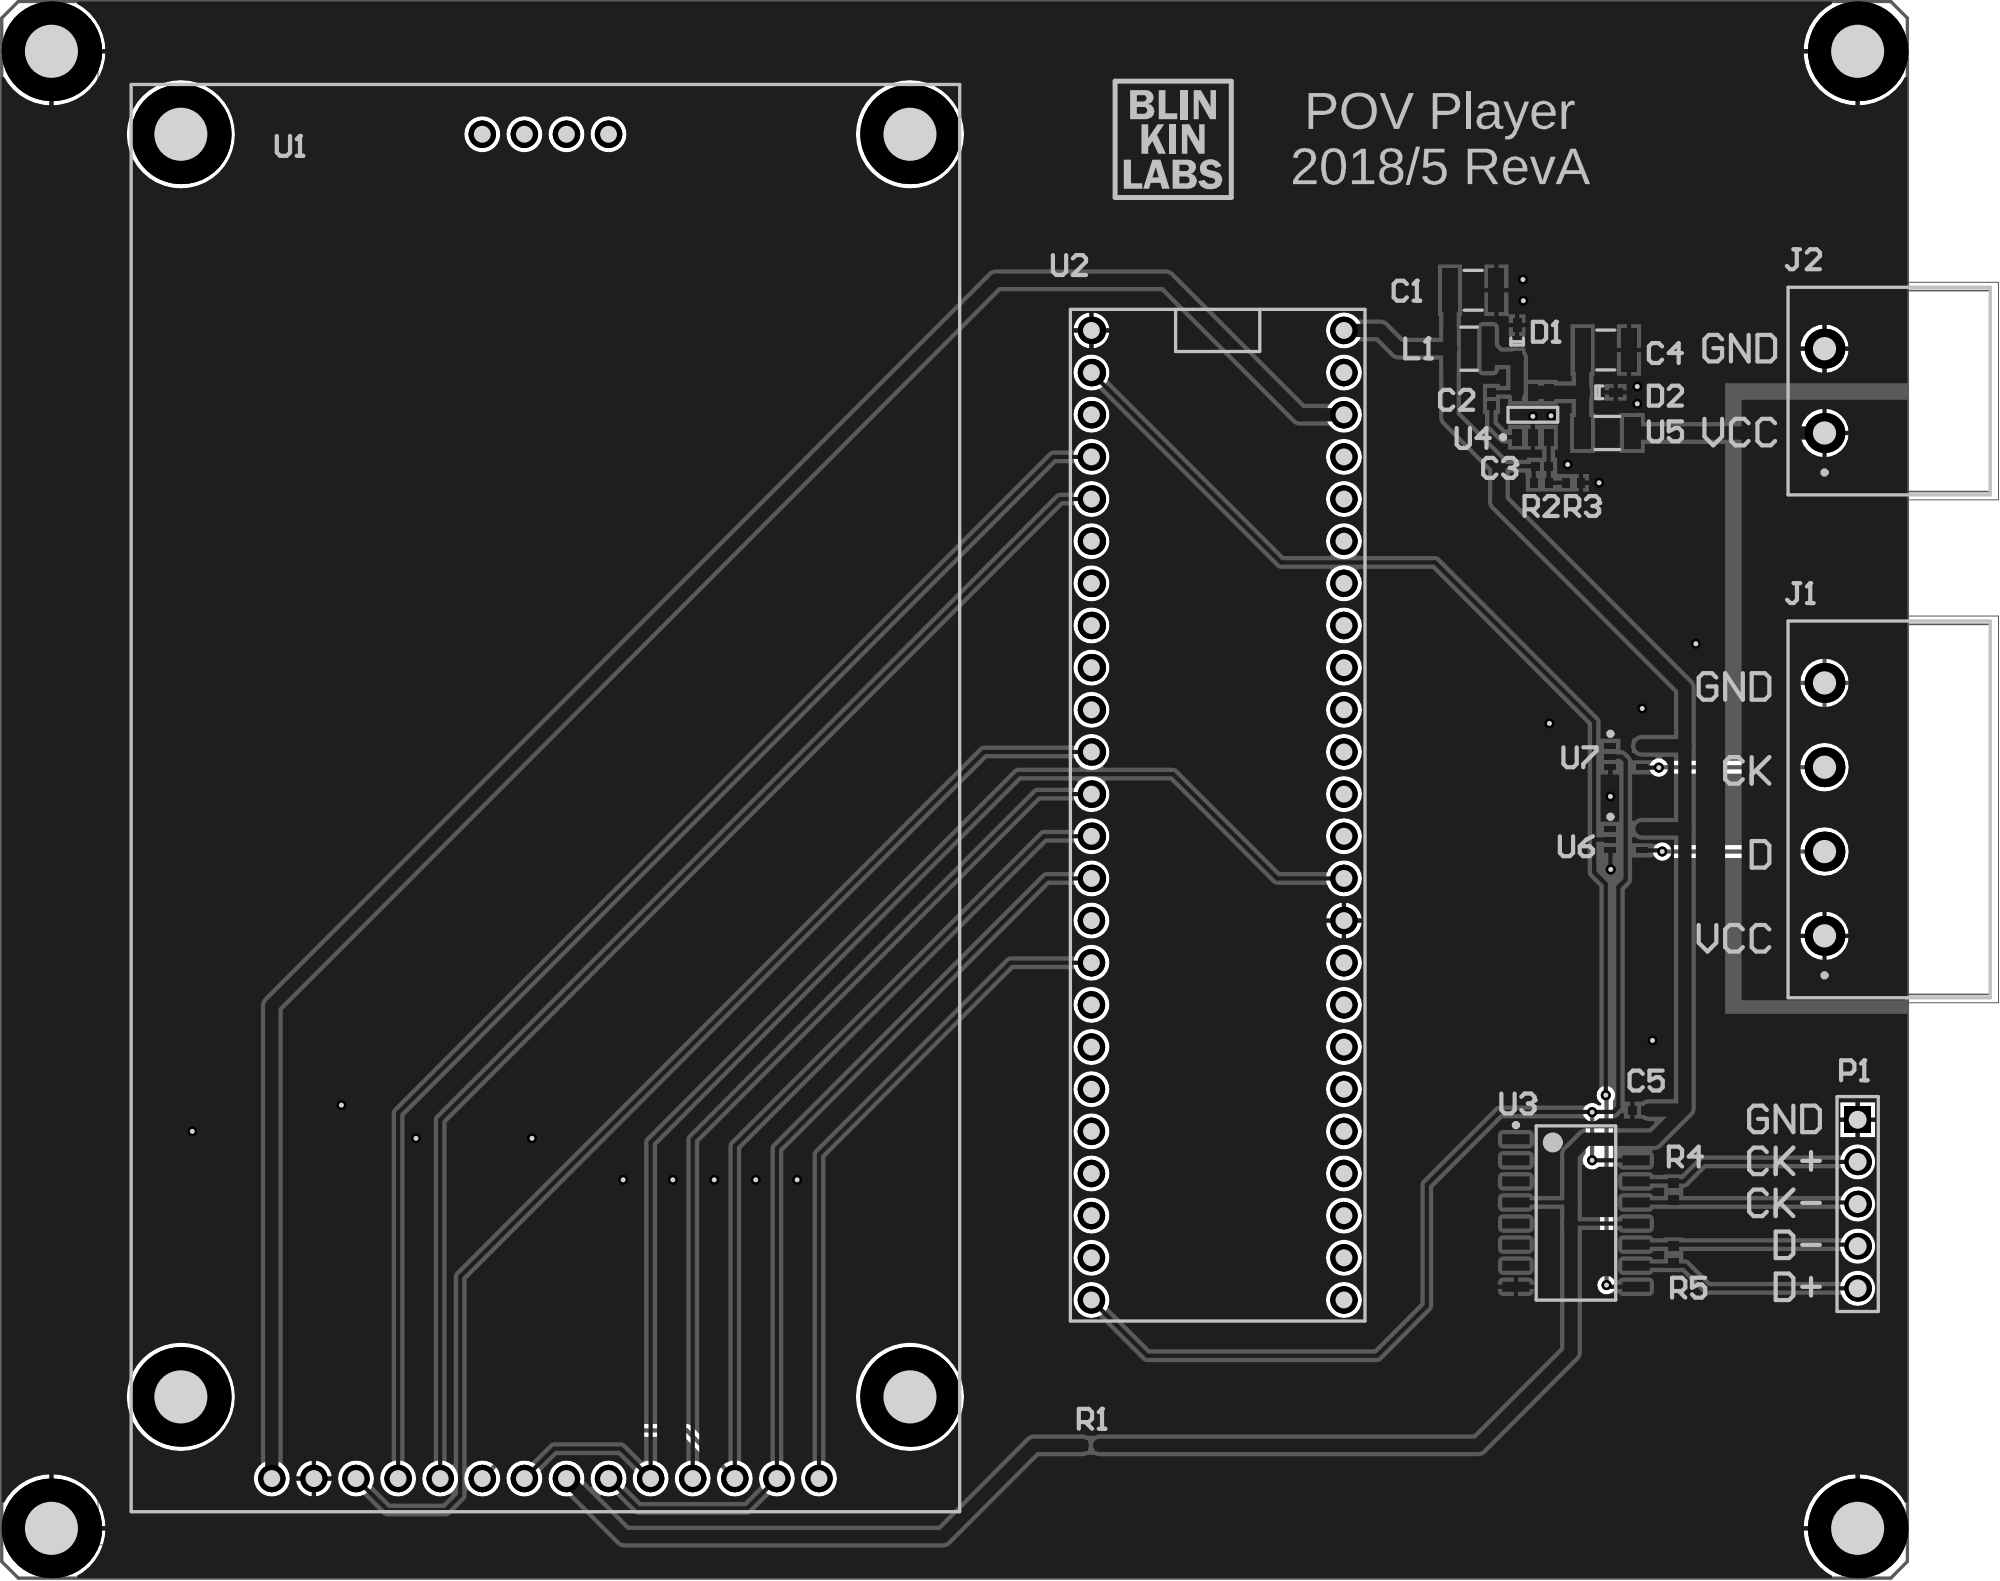
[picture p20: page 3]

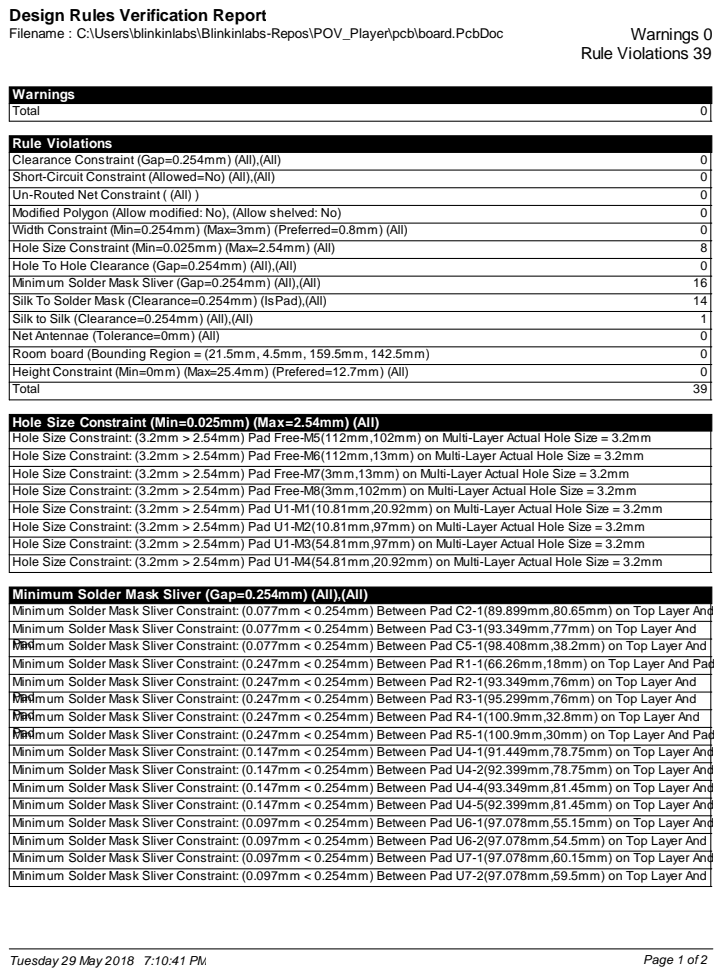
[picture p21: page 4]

Design Rules Verification Report

Hole Size Constraint (Min=0.025mm) (Max=2.54mm) (All)
Hole Size Constraint: (3.2mm > 2.54mm) Pad Free-M5(112mm,102mm) on Multi-Layer Actual Hole Size = 3.2mm
Hole Size Constraint: (3.2mm > 2.54mm) Pad Free-M6(112mm,13mm) on Multi-Layer Actual Hole Size = 3.2mm
Hole Size Constraint: (3.2mm > 2.54mm) Pad Free-M7(3mm,13mm) on Multi-Layer Actual Hole Size = 3.2mm
Hole Size Constraint: (3.2mm > 2.54mm) Pad Free-M8(3mm,102mm) on Multi-Layer Actual Hole Size = 3.2mm
Hole Size Constraint: (3.2mm > 2.54mm) Pad U1-M1(10.81mm,20.92mm) on Multi-Layer Actual Hole Size = 3.2mm
Hole Size Constraint: (3.2mm > 2.54mm) Pad U1-M2(10.81mm,97mm) on Multi-Layer Actual Hole Size = 3.2mm
Hole Size Constraint: (3.2mm > 2.54mm) Pad U1-M3(54.81mm,97mm) on Multi-Layer Actual Hole Size = 3.2mm
Hole Size Constraint: (3.2mm > 2.54mm) Pad U1-M4(54.81mm,20.92mm) on Multi-Layer Actual Hole Size = 3.2mm

Minimum Solder Mask Sliver (Gap=0.254mm) (All),(All)
Minimum Solder Mask Sliver Constraint: (0.077mm < 0.254mm) Between Pad C2-1(89.899mm,80.65mm) on Top Layer And
Minimum Solder Mask Sliver Constraint: (0.077mm < 0.254mm) Between Pad C3-1(93.349mm,77mm) on Top Layer And
PaMindimum Solder Mask Sliver Constraint: (0.077mm < 0.254mm) Between Pad C5-1(98.408mm,38.2mm) on Top Layer And
Minimum Solder Mask Sliver Constraint: (0.247mm < 0.254mm) Between Pad R1-1(66.26mm,18mm) on Top Layer And Pad
Minimum Solder Mask Sliver Constraint: (0.247mm < 0.254mm) Between Pad R2-1(93.349mm,76mm) on Top Layer And
PaMindimum Solder Mask Sliver Constraint: (0.247mm < 0.254mm) Between Pad R3-1(95.299mm,76mm) on Top Layer And
PaMindimum Solder Mask Sliver Constraint: (0.247mm < 0.254mm) Between Pad R4-1(100.9mm,32.8mm) on Top Layer And
PaMindimum Solder Mask Sliver Constraint: (0.247mm < 0.254mm) Between Pad R5-1(100.9mm,30mm) on Top Layer And Pad
Minimum Solder Mask Sliver Constraint: (0.147mm < 0.254mm) Between Pad U4-1(91.449mm,78.75mm) on Top Layer And
Minimum Solder Mask Sliver Constraint: (0.147mm < 0.254mm) Between Pad U4-2(92.399mm,78.75mm) on Top Layer And
Minimum Solder Mask Sliver Constraint: (0.147mm < 0.254mm) Between Pad U4-4(93.349mm,81.45mm) on Top Layer And
Minimum Solder Mask Sliver Constraint: (0.147mm < 0.254mm) Between Pad U4-5(92.399mm,81.45mm) on Top Layer And
Minimum Solder Mask Sliver Constraint: (0.097mm < 0.254mm) Between Pad U6-1(97.078mm,55.15mm) on Top Layer And
Minimum Solder Mask Sliver Constraint: (0.097mm < 0.254mm) Between Pad U6-2(97.078mm,54.5mm) on Top Layer And
Minimum Solder Mask Sliver Constraint: (0.097mm < 0.254mm) Between Pad U7-1(97.078mm,60.15mm) on Top Layer And
Minimum Solder Mask Sliver Constraint: (0.097mm < 0.254mm) Between Pad U7-2(97.078mm,59.5mm) on Top Layer And

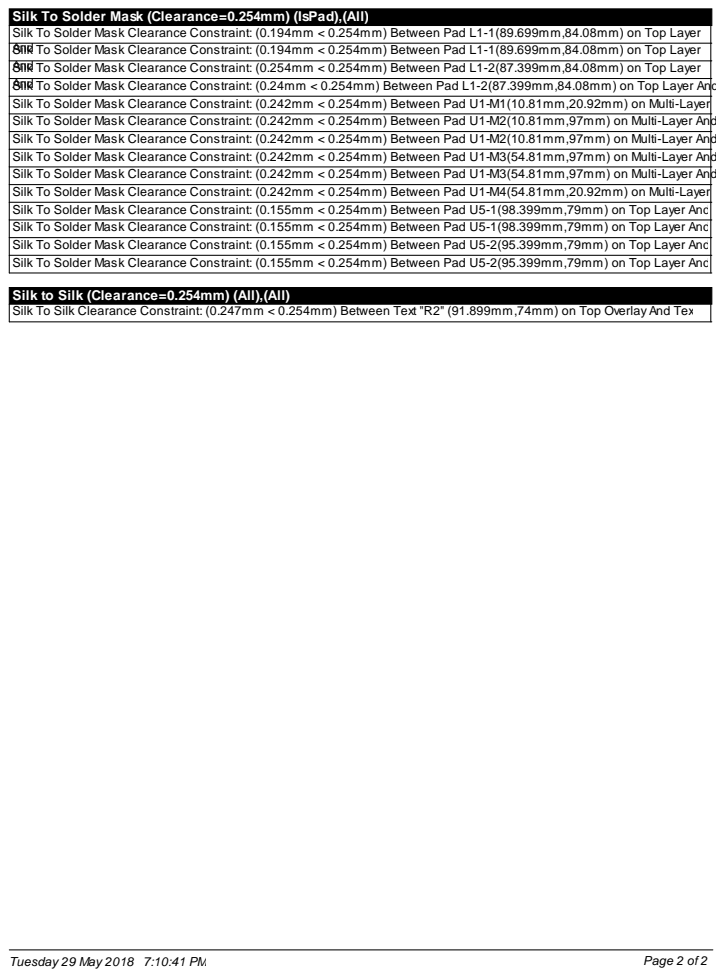
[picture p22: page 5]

Silk To Solder Mask (Clearance=0.254mm) (IsPad),(All)
Silk To Solder Mask Clearance Constraint: (0.194mm < 0.254mm) Between Pad L1-1(89.699mm,84.08mm) on Top Layer
ASinldk To Solder Mask Clearance Constraint: (0.194mm < 0.254mm) Between Pad L1-1(89.699mm,84.08mm) on Top Layer
ASinldk To Solder Mask Clearance Constraint: (0.254mm < 0.254mm) Between Pad L1-2(87.399mm,84.08mm) on Top Layer
ASinldk To Solder Mask Clearance Constraint: (0.24mm < 0.254mm) Between Pad L1-2(87.399mm,84.08mm) on Top Layer And
Silk To Solder Mask Clearance Constraint: (0.242mm < 0.254mm) Between Pad U1-M1(10.81mm,20.92mm) on Multi-Layer
Silk To Solder Mask Clearance Constraint: (0.242mm < 0.254mm) Between Pad U1-M2(10.81mm,97mm) on Multi-Layer And
Silk To Solder Mask Clearance Constraint: (0.242mm < 0.254mm) Between Pad U1-M3(54.81mm,97mm) on Multi-Layer And
Silk To Solder Mask Clearance Constraint: (0.242mm < 0.254mm) Between Pad U1-M4(54.81mm,20.92mm) on Multi-Layer
Silk To Solder Mask Clearance Constraint: (0.155mm < 0.254mm) Between Pad U5-1(98.399mm,79mm) on Top Layer And
Silk To Solder Mask Clearance Constraint: (0.155mm < 0.254mm) Between Pad U5-2(95.399mm,79mm) on Top Layer And

Silk to Silk (Clearance=0.254mm) (All),(All)
Silk To Silk Clearance Constraint: (0.247mm < 0.254mm) Between Text "R2" (91.899mm,74mm) on Top OverlayAnd Tex
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

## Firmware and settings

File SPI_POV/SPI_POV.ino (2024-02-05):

#include <SPI.h>
#include <SD.h>
#include <Adafruit_ILI9341.h>
#include <XPT2046_Touchscreen.h>

#include "MBI6020.h"
#include "MBI6120.h"
#include "APA102.h"

#include "LED_DATA.h"

#include "testpattern.h"

//*************************************************
// POV Player
//
// Designed for use with a Teensy 3.6
//
// Default configuration:

#define SPI_CLOCK_FREQUENCY_APA102 19000000
#define SPI_CLOCK_FREQUENCY_MBI6020 10000000

const unsigned int MAX_LED_COUNT = 500;
unsigned int ledCount = 240;
int fps = 2100;
int spiClockFrequency;
const char fileName[] = "POV.BMP";

//*************************************************
// Pin connections

// LED output pins (hardware SPI 1)
#define LED_MOSI 0
#define LED_SCK 32

// LCD and TS pins (hardware SPI 0)
#define TFT_MOSI 11
#define TFT_MISO 12
#define TFT_SCK 13

#define TFT_RESET 2
#define TFT_DC 3
#define TFT_CS 9

#define TOUCH_CS  10
#define TOUCH_IRQ 24

// Debug pin
#define FRAME_TIMING 1
//*************************************************

#define LOADBMP_IMPLEMENTATION
#include "readbmp.h"

#define PROTOCOL_APA102   0
#define PROTOCOL_MBI6020  1
#define PROTOCOL_MBI6120  2

int protocol = PROTOCOL_MBI6120;

struct Button {
  String text;
  int x;
  int y;
};

Button button_speedPlus  = {"Speed +", 10, 100};
Button button_speedMinus = {"Speed -", 10, 135};
//Button button_apa102     = {"apa102",  10, 170};
Button button_mbi6120    = {"mbi6120", 10, 170};
Button button_mbi6020    = {"mbi6020", 10, 205};
Button button_clockPlus  = {"Clock +", 10, 240};
Button button_clockMinus = {"Clock -", 10, 275};

MBI6120 mbi6120;

// Decoded bitmap geometry
unsigned char *imageData;
unsigned int imageWidth = 0;
unsigned int imageHeight = 0;

unsigned int frameDelay;

//Adafruit_ILI9341 tft = Adafruit_ILI9341(TFT_CS, TFT_DC,TFT_MOSI, TFT_SCK, TFT_RESET, TFT_MISO);
Adafruit_ILI9341 tft = Adafruit_ILI9341(TFT_CS, TFT_DC, TFT_RESET);

//XPT2046_Touchscreen ts(TOUCH_CS);
XPT2046_Touchscreen ts(TOUCH_CS, TOUCH_IRQ);

// Playback frame index
unsigned int currentFrame = 0;

// LED pixel buffer
LED_Data ledData[MAX_LED_COUNT];

uint16_t generativeBuffer[MAX_LED_COUNT*3];

// Test pattern to show on the LEDs, when an image cannot be loaded from the microSD card
void colorLoop16() {
  static float j = 0;
  static float f = 0;
  static float k = 0;

  const float brightness = 1;
  
  for (unsigned int i = 0; i < ledCount; i++) {
    generativeBuffer[i*3+0] = brightness*65535*(1+sin(i/2.0 + j/4.0       ));
    generativeBuffer[i*3+1] = brightness*65535*(1+sin(i/1.0 + f/9.0  + 2.1));
    generativeBuffer[i*3+2] = brightness*65535*(1+sin(i/3.0 + k/14.0 + 4.2));
  }
  
  j = j + .01;
  f = f + .01;
  k = k + .02;
}

void drawButton(const Button &button) {
  tft.setTextSize(2);
  tft.setCursor(button.x+5, button.y+10);
  tft.print(button.text);
  
  const int buttonWidth = 100;
  const int buttonHeight = 30;
  tft.drawRect(button.x,button.y,buttonWidth,buttonHeight, ILI9341_WHITE);
}

bool touchesButton(const Button &button, int touchX, int touchY) {
  const int buttonWidth = 100;
  const int buttonHeight = 30;
  return ((touchX >= button.x)
          && (touchX <= button.x + buttonWidth)
          && (touchY >= button.y)
          && (touchY <= button.y + buttonHeight));
}

void drawStats() {
  tft.fillRect(0,0,119,90, ILI9341_BLACK);
  tft.setCursor(0, 0);
  tft.setTextColor(ILI9341_WHITE);
  tft.setTextSize(1);
  tft.println("POV Player");
  tft.println("Blinkinlabs, LLC");
  
  tft.println("");
  tft.print("LEDs:");
  tft.println(ledCount);
  
  tft.print("Protocol:");
  if(protocol == PROTOCOL_APA102)
    tft.println("APA102");
  else if(protocol == PROTOCOL_MBI6020)
    tft.println("MBI6020");    
  else if(protocol == PROTOCOL_MBI6120)
    tft.println("MBI6120");
  else
    tft.println("?");
        
  tft.print("SPI Clock:");
  tft.print((int)spiClockFrequency/1000000);
  tft.println("MHz");
  
  tft.print("Speed:");
  tft.print((int)fps);
  tft.println("fps");
  tft.println("");
  tft.print("Image:");
  tft.println(fileName);
  tft.print("Width:");
  tft.println(imageWidth);
  tft.print("Height:");
  tft.println(imageHeight);
}

void drawScreen() {
  tft.fillScreen(ILI9341_BLACK);

  // Draw some buttons
  drawButton(button_speedPlus);
  drawButton(button_speedMinus);
  //drawButton(button_apa102);
  drawButton(button_mbi6120);
  drawButton(button_mbi6020);
  drawButton(button_clockMinus);
  drawButton(button_clockPlus);

  // Draw the image
  uint16_t xOffset = 121;
  uint16_t yOffset = 1;
  
  for(unsigned int x = 0; x < imageWidth; x++) {
    for(unsigned int y = 0; y < imageHeight; y++) {
      const uint16_t color = tft.color565(
        imageData[x*imageHeight*3 + y*3 + 0],
        imageData[x*imageHeight*3 + y*3 + 1],
        imageData[x*imageHeight*3 + y*3 + 2]
        );
      tft.drawPixel(x + xOffset, y + yOffset, color);
    }
  }

  // And a frame around the image
  const uint16_t borderColor = tft.color565(0,0,255);
  tft.drawRect(xOffset - 1, yOffset - 1, imageWidth + 2, imageHeight + 2, borderColor);

  drawStats();
}

void setup() {
  // Initialize USB serial (for debug messages)
  Serial.begin(9600);
//  delay(3000);
  
  Serial.println("Blinkinlabs POV Player");
  Serial.println("Version 0.1");

  Serial.println("Starting TFT");
  tft.begin();
  
  Serial.println("Starting TS");
  ts.begin();

  Serial.println("Starting SD");
  if (!SD.begin(BUILTIN_SDCARD)) {
    Serial.println("failed to initialize SD card!");
  }

  Serial.println("Loading Image");
  unsigned int retval;
  retval = loadbmp_decode_file(fileName, &imageData, &imageWidth, &imageHeight, LOADBMP_RGB);

  if(retval == LOADBMP_NO_ERROR) {
    Serial.println("Image loaded");

    // Set the led count based on the image height
    ledCount = min(MAX_LED_COUNT, imageHeight);
  }
  else {
    Serial.println("Error loading image, switching to test pattern");

    imageWidth = TESTPATTERN_WIDTH;
    imageHeight = TESTPATTERN_HEIGHT;
    imageData = (unsigned char*) testpatternData;

    ledCount = min(MAX_LED_COUNT, imageHeight);
    
    fps = TESTPATTERN_FPS;
  }

  pinMode(FRAME_TIMING, OUTPUT);
  digitalWriteFast(FRAME_TIMING, LOW);


  Serial.println("Starting LED output");
  if(protocol == PROTOCOL_APA102) {
    spiClockFrequency = SPI_CLOCK_FREQUENCY_APA102;
    apa102_begin(ledCount, spiClockFrequency);
  }
  else if(protocol == PROTOCOL_MBI6020) {
    spiClockFrequency = SPI_CLOCK_FREQUENCY_MBI6020;
    mbi6020_begin(ledCount, spiClockFrequency);
  }
  else if(protocol == PROTOCOL_MBI6120) {
    mbi6120.begin();
  }

  frameDelay = 1000000/fps;

  // Draw some stats
  drawScreen();
}

bool lastTouchState = false;
bool drewUnderflowNotice = false;

void loop() {
  elapsedMicros loopTime;

  bool currentTouchState = ts.touched();

  if((currentTouchState == true) && (lastTouchState == false)) {
    TS_Point p = ts.getPoint();

    // Determined experimentally
    const int mappedX = map(p.y,3800,300,0,240);
    const int mappedY = map(p.x,3900,370,0,320);

    Serial.print(p.x);
    Serial.print(",");
    Serial.println(p.y);

    if(touchesButton(button_speedPlus,mappedX,mappedY)) {
      // Speed +
      if(fps >= 100)
        fps += 100;
      else if(fps >= 10)
        fps += 10;
      else
        fps += 1;

      frameDelay = 1000000/fps;
      
      drawStats();
      drewUnderflowNotice = false;
    }
    else if(touchesButton(button_speedMinus,mappedX,mappedY)) {
      // Speed -
      if(fps > 100)
        fps -= 100;
      else if(fps > 10)
        fps -= 10;
      else if(fps > 1)
        fps -= 1;

      frameDelay = 1000000/fps;
      
      drawStats();
      drewUnderflowNotice = false;
    }
//    else if(touchesButton(button_apa102,mappedX,mappedY)) {
//      protocol = PROTOCOL_APA102;
//      spiClockFrequency = SPI_CLOCK_FREQUENCY_APA102;
//      button_apa102_begin(ledCount, spiClockFrequency);
//      
//      drawStats();
//      drewUnderflowNotice = false;
//    }
    else if(touchesButton(button_mbi6020,mappedX,mappedY)) {
      protocol = PROTOCOL_MBI6020;
      spiClockFrequency = SPI_CLOCK_FREQUENCY_MBI6020;
      mbi6020_begin(ledCount, spiClockFrequency);
      
      drawStats();
      drewUnderflowNotice = false;
    }
    else if(touchesButton(button_mbi6120,mappedX,mappedY)) {
      protocol = PROTOCOL_MBI6120;
      mbi6120.begin();
      
      drawStats();
      drewUnderflowNotice = false;
    }
    else if(touchesButton(button_clockPlus,mappedX,mappedY)) {
      // Clock speed +
      if (spiClockFrequency < 39000000)
        spiClockFrequency += 1000000;

      drawStats();
      drewUnderflowNotice = false;
    }
    else if(touchesButton(button_clockMinus,mappedX,mappedY)) {
      // Clock speed -
      if (spiClockFrequency > 1000000)
        spiClockFrequency -= 1000000;

      drawStats();
      drewUnderflowNotice = false;
    }
  }
  lastTouchState = currentTouchState;

  const uint8_t *frameData = imageData + currentFrame*imageHeight*3;

  digitalWriteFast(FRAME_TIMING, HIGH);

  if(protocol == PROTOCOL_APA102)
    apa102_SendData(frameData, ledCount, spiClockFrequency);
  else if(protocol == PROTOCOL_MBI6020)
    send16bitGrayscaleData(frameData, ledCount, spiClockFrequency);
  else if(protocol == PROTOCOL_MBI6120) {
    //mbi6120.send(frameData, ledCount);
      
    // TODO: Discarding image playback for generative
    ledCount = 5;
    colorLoop16();
    mbi6120.send(generativeBuffer, ledCount);
  }

    
  digitalWriteFast(FRAME_TIMING, LOW);

  currentFrame++;
  if(currentFrame == imageWidth)
    currentFrame = 0;
  

// Note: this takes ~20us
  // If we exceeded loop time, draw a dot on the LCD to indicate this.
  if((loopTime > frameDelay) && (currentTouchState == false)) {
    if(!drewUnderflowNotice) {
      tft.drawPixel(90,52, ILI9341_RED);
      drewUnderflowNotice = true;
    }
  }
  
  while(loopTime < frameDelay);
}

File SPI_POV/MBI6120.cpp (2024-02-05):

#include <Arduino.h>
#include "MBI6120.h"

#include <SPI.h>

// TODO: Make me configurable?
// TODO: Replace driver on board, switch to data output
#define dataPin 32  

void MBI6120::begin() {
  //TODO: Pin config
//  SPI1.stop();
  pinMode(dataPin, OUTPUT);
  digitalWrite(dataPin, LOW);
}


void MBI6120::send(const uint8_t * data, size_t count) {
/*
# Packet structure

[Header][ICn data][ICn-1 data]...[Ic1 data]

## Header

[H1][CLK][CMD][NUM][gap]

| Section  | Bits    | Value                               | Function            |
| ===      | ===     | ===                                 | ===                 |
| H1       | [35:24] | 12’b111111111111                    | Data rate detection |
| reserved | [23:22] | xx (don’t care)                     |                     |
| CLK      | [21:20] | 0=5.2MHz,1=2.6MHz,2=1,3MHz,3=650kHz | GCLK setting        |
| CMD      | [19:12] | 8’b00000000=data, 8’b01010101=reset | Packet type         |
| reserved | [11:10] | xx (don’t care)                     |                     |
| NUM      | [9:0]   | 1-511                               | Number of ICs       |

The gap is a stretched clock bit.

## Data

Data is 12-bit values for each output, MSB first. OUTA is sent first, then OUTB, then OUTC.

*/

  // H1
  for(int i = 0; i < 12; i++) {
    // Let's start with 4us per bit
    digitalWriteFast(dataPin, HIGH);
    delayMicroseconds(1);
    digitalWriteFast(dataPin, HIGH);
    delayMicroseconds(3);
    digitalWriteFast(dataPin, LOW);
    delayMicroseconds(1);
  }
  
  // Reserved
  for(int i = 0; i < 2; i++) {
    digitalWriteFast(dataPin, HIGH);
    delayMicroseconds(1);
    digitalWriteFast(dataPin, LOW);
    delayMicroseconds(3);
    digitalWriteFast(dataPin, LOW);
    delayMicroseconds(1);
  }

  // CLK
  for(int i = 0; i < 2; i++) {
    digitalWriteFast(dataPin, HIGH);
    delayMicroseconds(1);
    digitalWriteFast(dataPin, LOW);
    delayMicroseconds(3);
    digitalWriteFast(dataPin, LOW);
    delayMicroseconds(1);
  }

  // CMD
  for(int i = 0; i < 8; i++) {
    digitalWriteFast(dataPin, HIGH);
    delayMicroseconds(1);
    digitalWriteFast(dataPin, LOW);
    delayMicroseconds(3);
    digitalWriteFast(dataPin, LOW);
    delayMicroseconds(1);
  }

  // Reserved
  for(int i = 0; i < 2; i++) {
    digitalWriteFast(dataPin, HIGH);
    delayMicroseconds(1);
    digitalWriteFast(dataPin, LOW);
    delayMicroseconds(3);
    digitalWriteFast(dataPin, LOW);
    delayMicroseconds(1);
  }

  // NUM
  for(int i = 0; i < 10; i++) {
    digitalWriteFast(dataPin, HIGH);
    delayMicroseconds(1);
    digitalWriteFast(dataPin, (count >> (9-i)) & 0x01);
    delayMicroseconds(3);
    digitalWriteFast(dataPin, LOW);
    delayMicroseconds(1);
  }

  // gap
  digitalWriteFast(dataPin, HIGH);
  delayMicroseconds(9);
  digitalWriteFast(dataPin, LOW);
  delayMicroseconds(1);

  //data
  for(int led = 0; led < count; led++) {
    for(int channel = 0; channel < 3; channel++) {
      int val = (data[led*3 + channel]) << 4;
      
      for(int index = 0; index < 12; index++) {
        digitalWriteFast(dataPin, HIGH);
        delayMicroseconds(1);
        
        digitalWriteFast(dataPin, (val >> (11-index)) & 0x01);
        delayMicroseconds(3);
        digitalWriteFast(dataPin, LOW);
        delayMicroseconds(1);
      }
    }

    // gap
    digitalWriteFast(dataPin, HIGH);
    delayMicroseconds(9);
    digitalWriteFast(dataPin, LOW);
    delayMicroseconds(1);
  }
}


void MBI6120::send(const uint16_t * data, size_t count) {
/*
# Packet structure

[Header][ICn data][ICn-1 data]...[Ic1 data]

## Header

[H1][CLK][CMD][NUM][gap]

| Section  | Bits    | Value                               | Function            |
| ===      | ===     | ===                                 | ===                 |
| H1       | [35:24] | 12’b111111111111                    | Data rate detection |
| reserved | [23:22] | xx (don’t care)                     |                     |
| CLK      | [21:20] | 0=5.2MHz,1=2.6MHz,2=1,3MHz,3=650kHz | GCLK setting        |
| CMD      | [19:12] | 8’b00000000=data, 8’b01010101=reset | Packet type         |
| reserved | [11:10] | xx (don’t care)                     |                     |
| NUM      | [9:0]   | 1-511                               | Number of ICs       |

The gap is a stretched clock bit.

## Data

Data is 12-bit values for each output, MSB first. OUTA is sent first, then OUTB, then OUTC.

*/

  // H1
  for(int i = 0; i < 12; i++) {
    // Let's start with 4us per bit
    digitalWriteFast(dataPin, HIGH);
    delayMicroseconds(1);
    digitalWriteFast(dataPin, HIGH);
    delayMicroseconds(3);
    digitalWriteFast(dataPin, LOW);
    delayMicroseconds(1);
  }
  
  // Reserved
  for(int i = 0; i < 2; i++) {
    digitalWriteFast(dataPin, HIGH);
    delayMicroseconds(1);
    digitalWriteFast(dataPin, LOW);
    delayMicroseconds(3);
    digitalWriteFast(dataPin, LOW);
    delayMicroseconds(1);
  }

  // CLK
  for(int i = 0; i < 2; i++) {
    digitalWriteFast(dataPin, HIGH);
    delayMicroseconds(1);
    digitalWriteFast(dataPin, LOW);
    delayMicroseconds(3);
    digitalWriteFast(dataPin, LOW);
    delayMicroseconds(1);
  }

  // CMD
  for(int i = 0; i < 8; i++) {
    digitalWriteFast(dataPin, HIGH);
    delayMicroseconds(1);
    digitalWriteFast(dataPin, LOW);
    delayMicroseconds(3);
    digitalWriteFast(dataPin, LOW);
    delayMicroseconds(1);
  }

  // Reserved
  for(int i = 0; i < 2; i++) {
    digitalWriteFast(dataPin, HIGH);
    delayMicroseconds(1);
    digitalWriteFast(dataPin, LOW);
    delayMicroseconds(3);
    digitalWriteFast(dataPin, LOW);
    delayMicroseconds(1);
  }

  // NUM
  for(int i = 0; i < 10; i++) {
    digitalWriteFast(dataPin, HIGH);
    delayMicroseconds(1);
    digitalWriteFast(dataPin, (count >> (9-i)) & 0x01);
    delayMicroseconds(3);
    digitalWriteFast(dataPin, LOW);
    delayMicroseconds(1);
  }

  // gap
  digitalWriteFast(dataPin, HIGH);
  delayMicroseconds(9);
  digitalWriteFast(dataPin, LOW);
  delayMicroseconds(1);

  //data
  for(int led = 0; led < count; led++) {
    for(int channel = 0; channel < 3; channel++) {
      int val = (data[led*3 + channel]) >> 4;
      
      for(int index = 0; index < 12; index++) {
        digitalWriteFast(dataPin, HIGH);
        delayMicroseconds(1);
        
        digitalWriteFast(dataPin, (val >> (11-index)) & 0x01);
        delayMicroseconds(3);
        digitalWriteFast(dataPin, LOW);
        delayMicroseconds(1);
      }
    }

    // gap
    digitalWriteFast(dataPin, HIGH);
    delayMicroseconds(9);
    digitalWriteFast(dataPin, LOW);
    delayMicroseconds(1);
  }
}

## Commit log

2018-05-29 Add instructions and Arduino sketch
2018-05-29 RevA release
    [2018-05-29 POV_Player RevA BOM.xls, 2018-05-29 POV_Player RevA.step, POV_Player.PrjPCB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]
2018-05-30 Add touchscreen support, APA102 support
    [POV_Player.PrjPCB, board.PcbDoc, board.SchDoc]
2018-06-02 Fix chip select lines in software
    [POV_Player.PrjPCB, board.PcbDoc]
2018-06-04 Improve playback speed
    [board.PcbDoc, board.SchDoc]
2018-06-04 Release RevA firmware, add sample images
